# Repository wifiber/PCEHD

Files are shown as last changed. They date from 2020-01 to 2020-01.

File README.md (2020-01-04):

PC Engine / Turbo Grafx HDMI output board (PCEHD)
==============

Overview
--------------------------
PCEHD is a project to deliver HDMI video/audio from the PC Engine/Turbo-Grafx utilizing the digital video bus exposed on the expansion connector. The goal is to take the digital video directly from the console and upscale it to 1080p.

Features
--------------------------
* None yet

TODO
--------------------------
* Finish initial verion of schematic (DONE)
* Finish initial verion of HDL code (need help here)
* Get test PCBs made (PENDING)
* Get HDMI video output working (PENDING)
* Get analog audio encoded into HDMI stream (PENDING)

Long Term TODO
--------------------------
* Optical Drive Emulation (PENDING)
* Flash cart / SD card option (PENDING)

Installation
--------------------------
Attach PCEHD to the expansion port on your PC Engine or Turbo-Grafx console. Enjoy lag free 1080p.

Usage
--------------------------

More info and discussion
--------------------------
See the docs folder for a collection of PC Engine dev material.
There are good schematics online and the TurboGrafx-16 Unit Service Manual provides an excellent block diagram that really makes understanding the interaction of the 3 main HuC62xx chips much easier.

The aim of the PCEHD project is to reproduce the IC112 (HuC6260) inside the FPGA on the PCEHD. HuC6260, the Video Color Encoder, has an internal palette used for the background and sprites. It is made up of 512 9-bit entries. The first 256 entries are for the backgrounds and the last 256 are for the sprites. 
When the console first boots up, the VCE is initialized with palette data from the Hu Card by the CPU. According to the schematics, the data lines from the HU card all have pull-ups to 5v. This is why when you start the console with no game inserted you get a white screen - the VCE palette get filled with all 0xFF for the RGB data, which then returns white on the screen.

Requirement 1. - The FPGA needs to snoop on the CPU -> VCE communication when the console first boots. The FPGA needs to see what the CPU is loading into the VCE internal palette (All 512 entries). This is possible since both the data and address bus are exposed on the expansion connector. So the FPGA should have insight to the CPU -> VCE communication.
Using the FPGA core for the HuC6260, if we are connected to the same address and data bus as the physical VCE, we should be able to get the CPU to update both the physical VCE and the FPGA-VCE at the same time, since the FPGA-VCE is listening at the same address as the VCE inside the console.  

Once the console boots up and the CPU has successfully loaded the VCE pallette, the VDC now comes into play. The VDC and VCE share a 9-bit video bus (This is separate from the data bus the CPU used to load the palette in the steps above). 
The VDC will be placing data on the video bus, this data is a 9-bit address into the VCE palette (9-bits = 512 entries). The VCE takes these addresses, does the lookup into its palette and returns the 9-bit RGB code.  

Requirement 2. - The FPGA needs to snoop on the VDC -> VCE communication. The VDC will be placing addresses on the video bus. Those addresses reference colors stored in the 512 entry VCE palette table. Once the VCE looks up the address, the data it returns is 9-bit RGB data. This 9-bit RGB data is used inside the HuC6260 to generate the analog RGB and composite signals. Assuming the FPGA knows what RGB values are stored in each VCE table entry.(Req 1)
Also, assuming the FPGA knows what the VCE will display next based on what palette address the VDC was placing on the video bus - we should be able to recreate the scanline that the VCE would have displayed. From there its a matter of line-doubling and tweaking to fit the 1080p standard.
Again, using the FPGA core for the HuC6260 should give us a VCE that acts just like the phyiscal one inside the console. Once we have the VCE outputting the RGB data, its a matter of formatting it into the correct HDMI standard.

Thanks to marqs for the OSSC/CPS2_HDMI projects that are the majority of the base material for this project
https://github.com/marqs85

Thanks to the FPGAPCE project on github for a nice HDL example of the entire console.
https://github.com/Torlus/FPGAPCE

Thanks to skum for the very clean and well layed out KiCad symbol and footprint of the expansion connector. Its 69 pins but somehow his symbol is manageable.
https://github.com/skumlos/pcengine-rgb-addon

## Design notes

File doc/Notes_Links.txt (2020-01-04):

https://www.thingiverse.com/thing:3245238
https://oshpark.com/shared_projects/jqp6SYQ6

Exp Port Connector
U1 3x23 Pin 2.54mm pitch header. 
Samtec SSQ-123-02-T-T-RA, SSW-123-02-T-T-RA (or -F-T-RA versions).

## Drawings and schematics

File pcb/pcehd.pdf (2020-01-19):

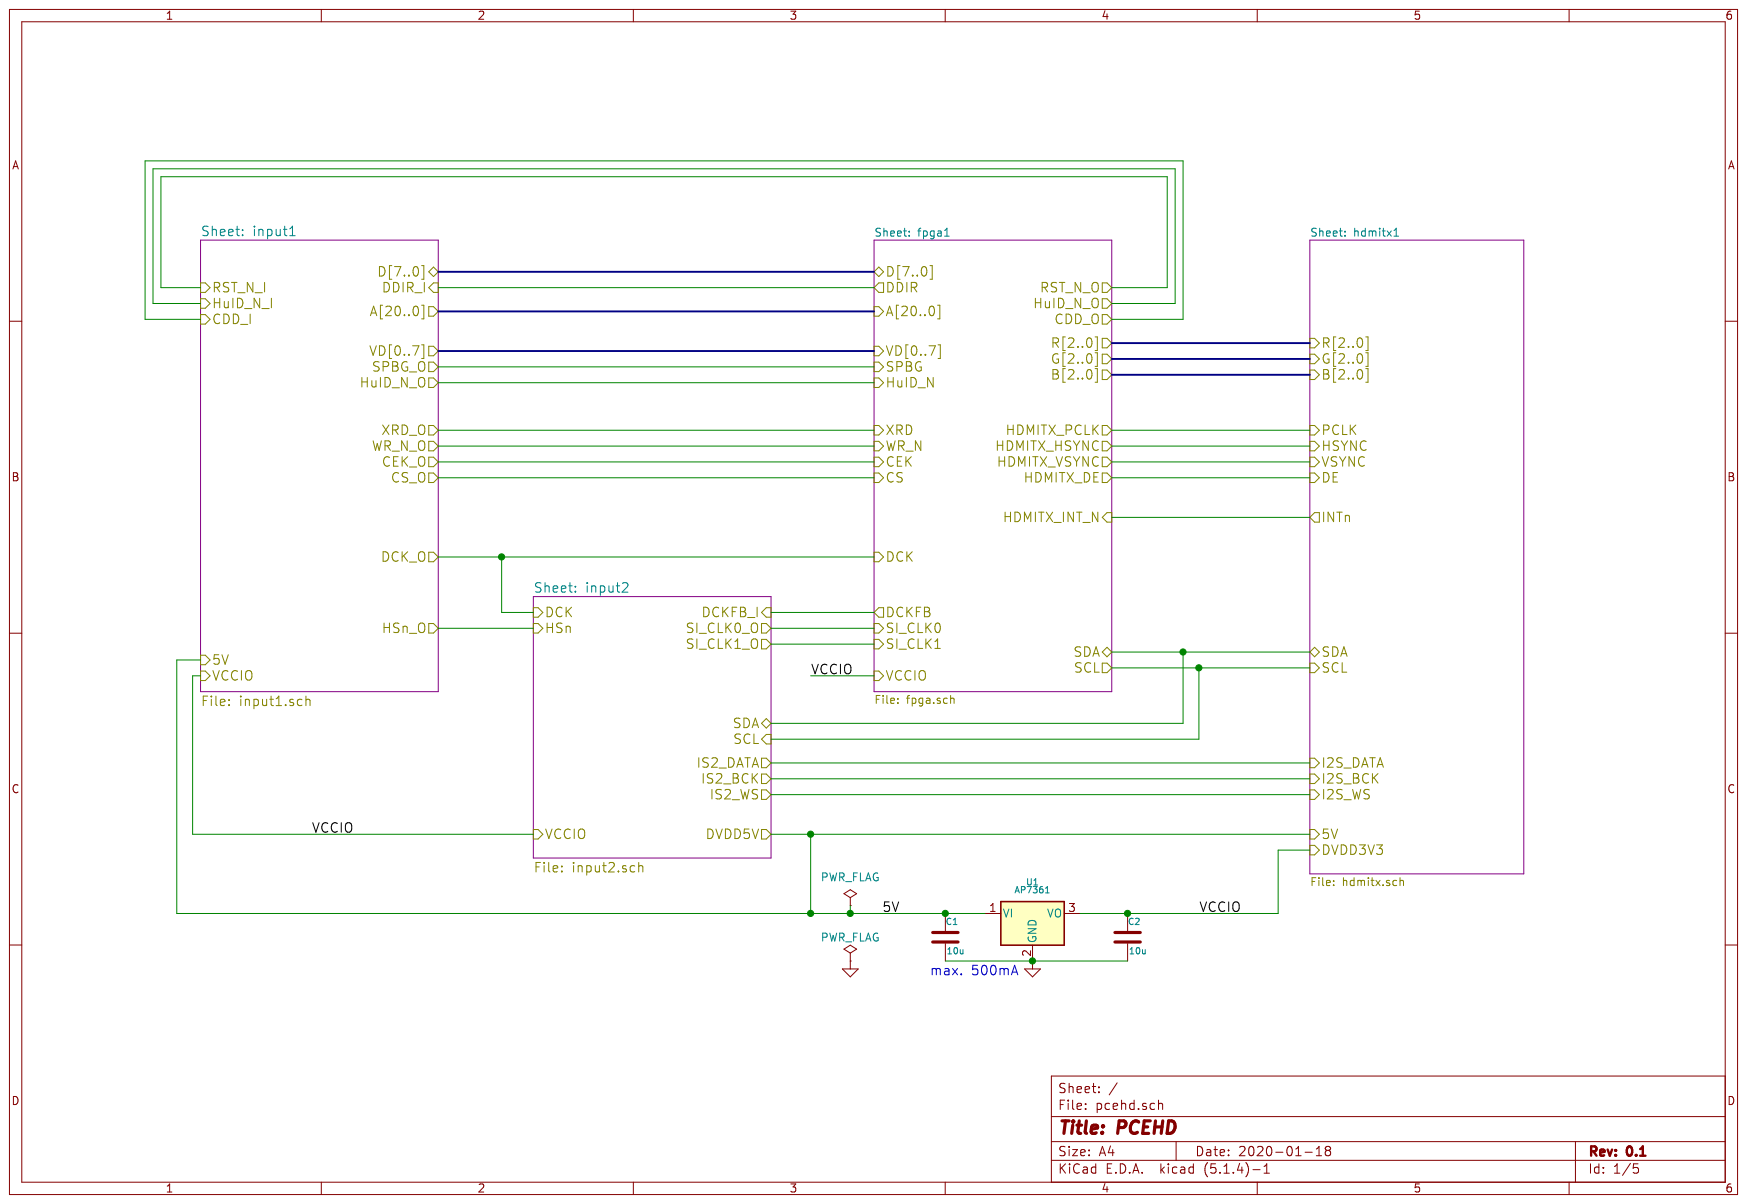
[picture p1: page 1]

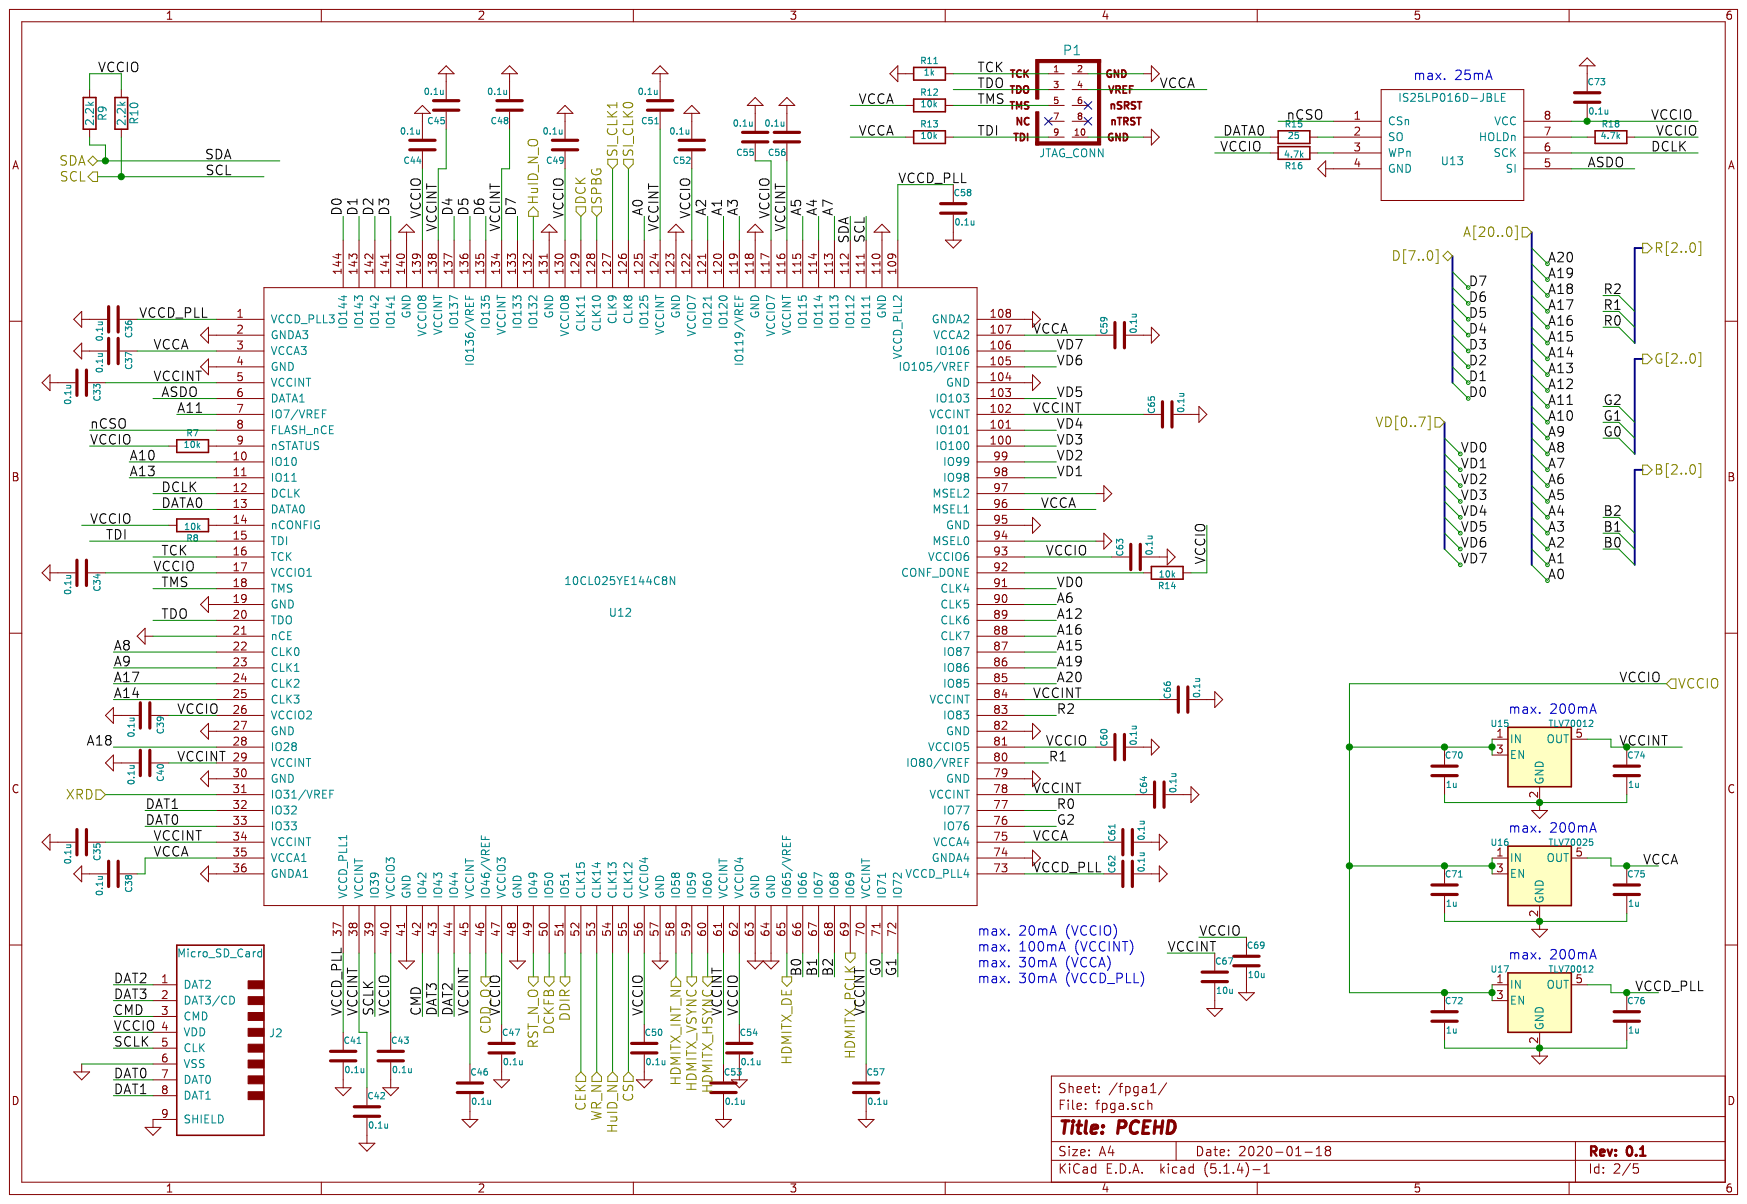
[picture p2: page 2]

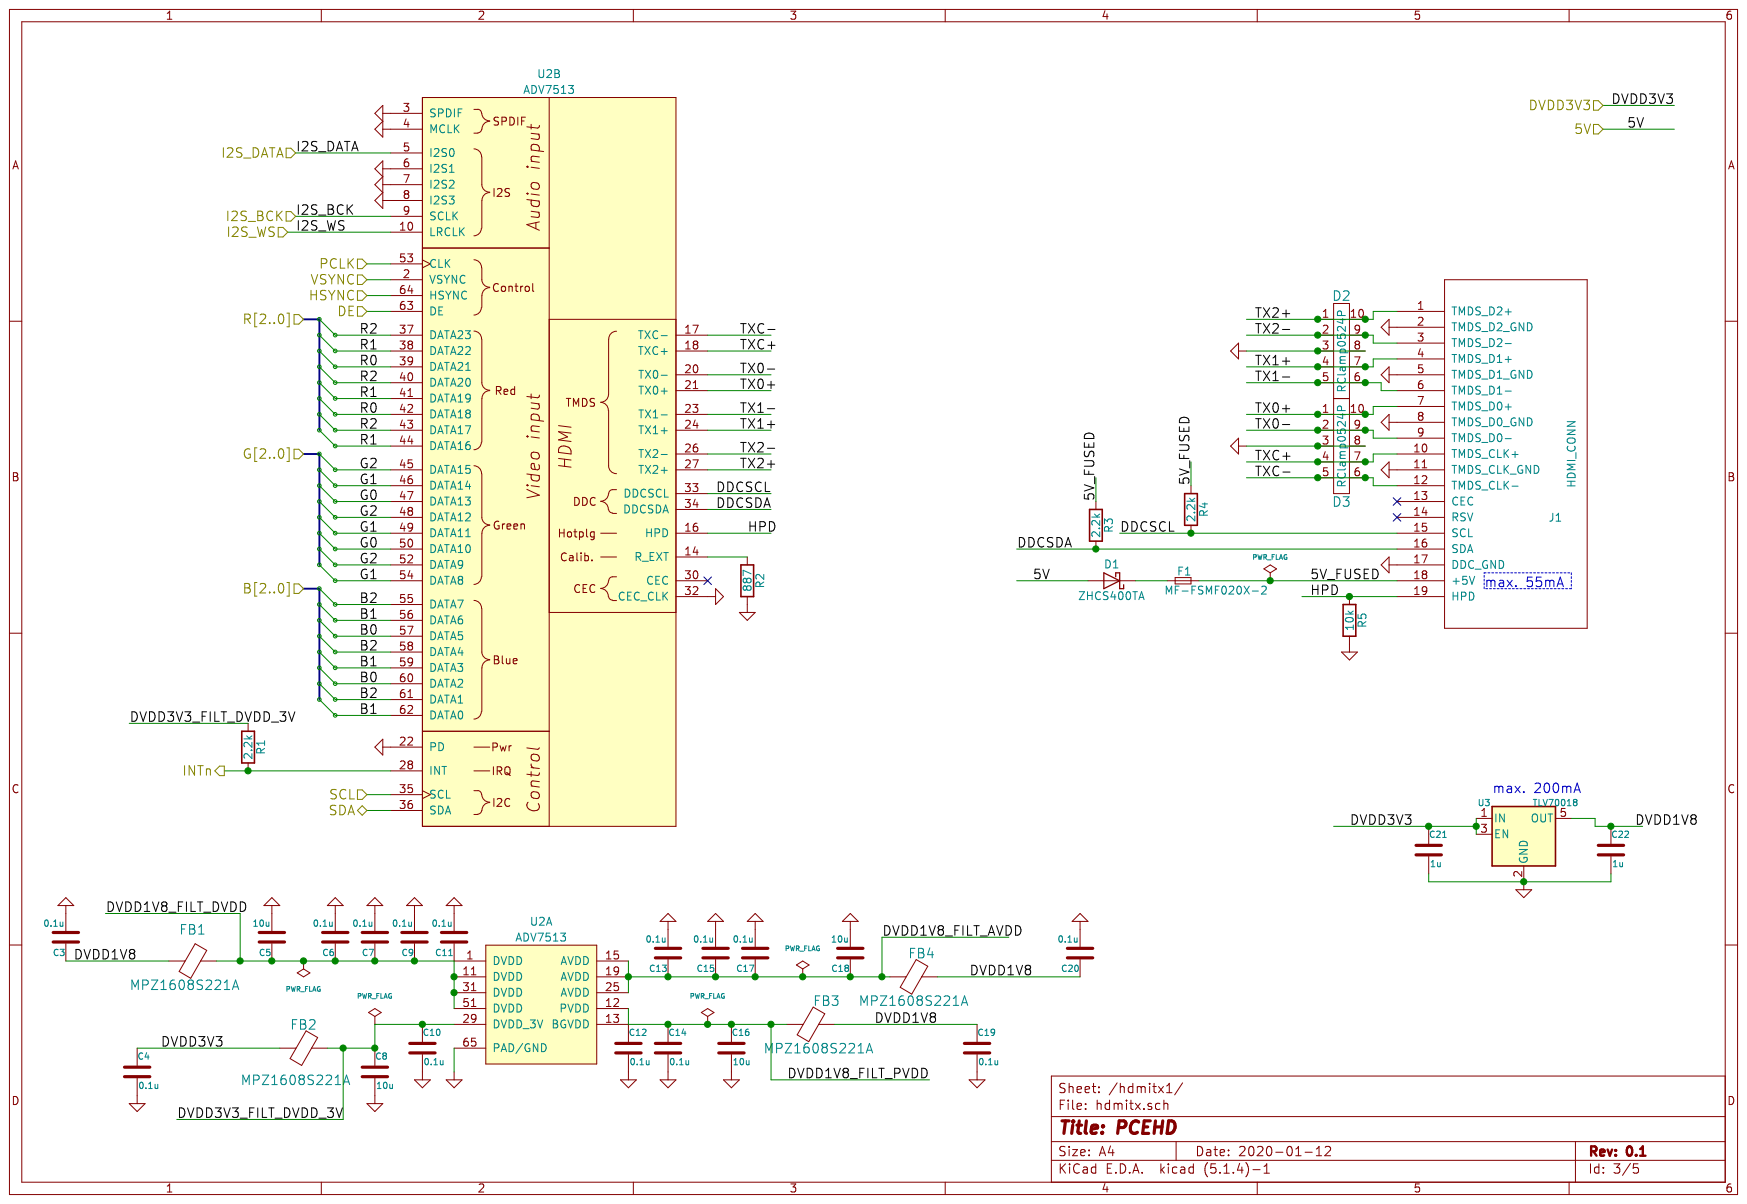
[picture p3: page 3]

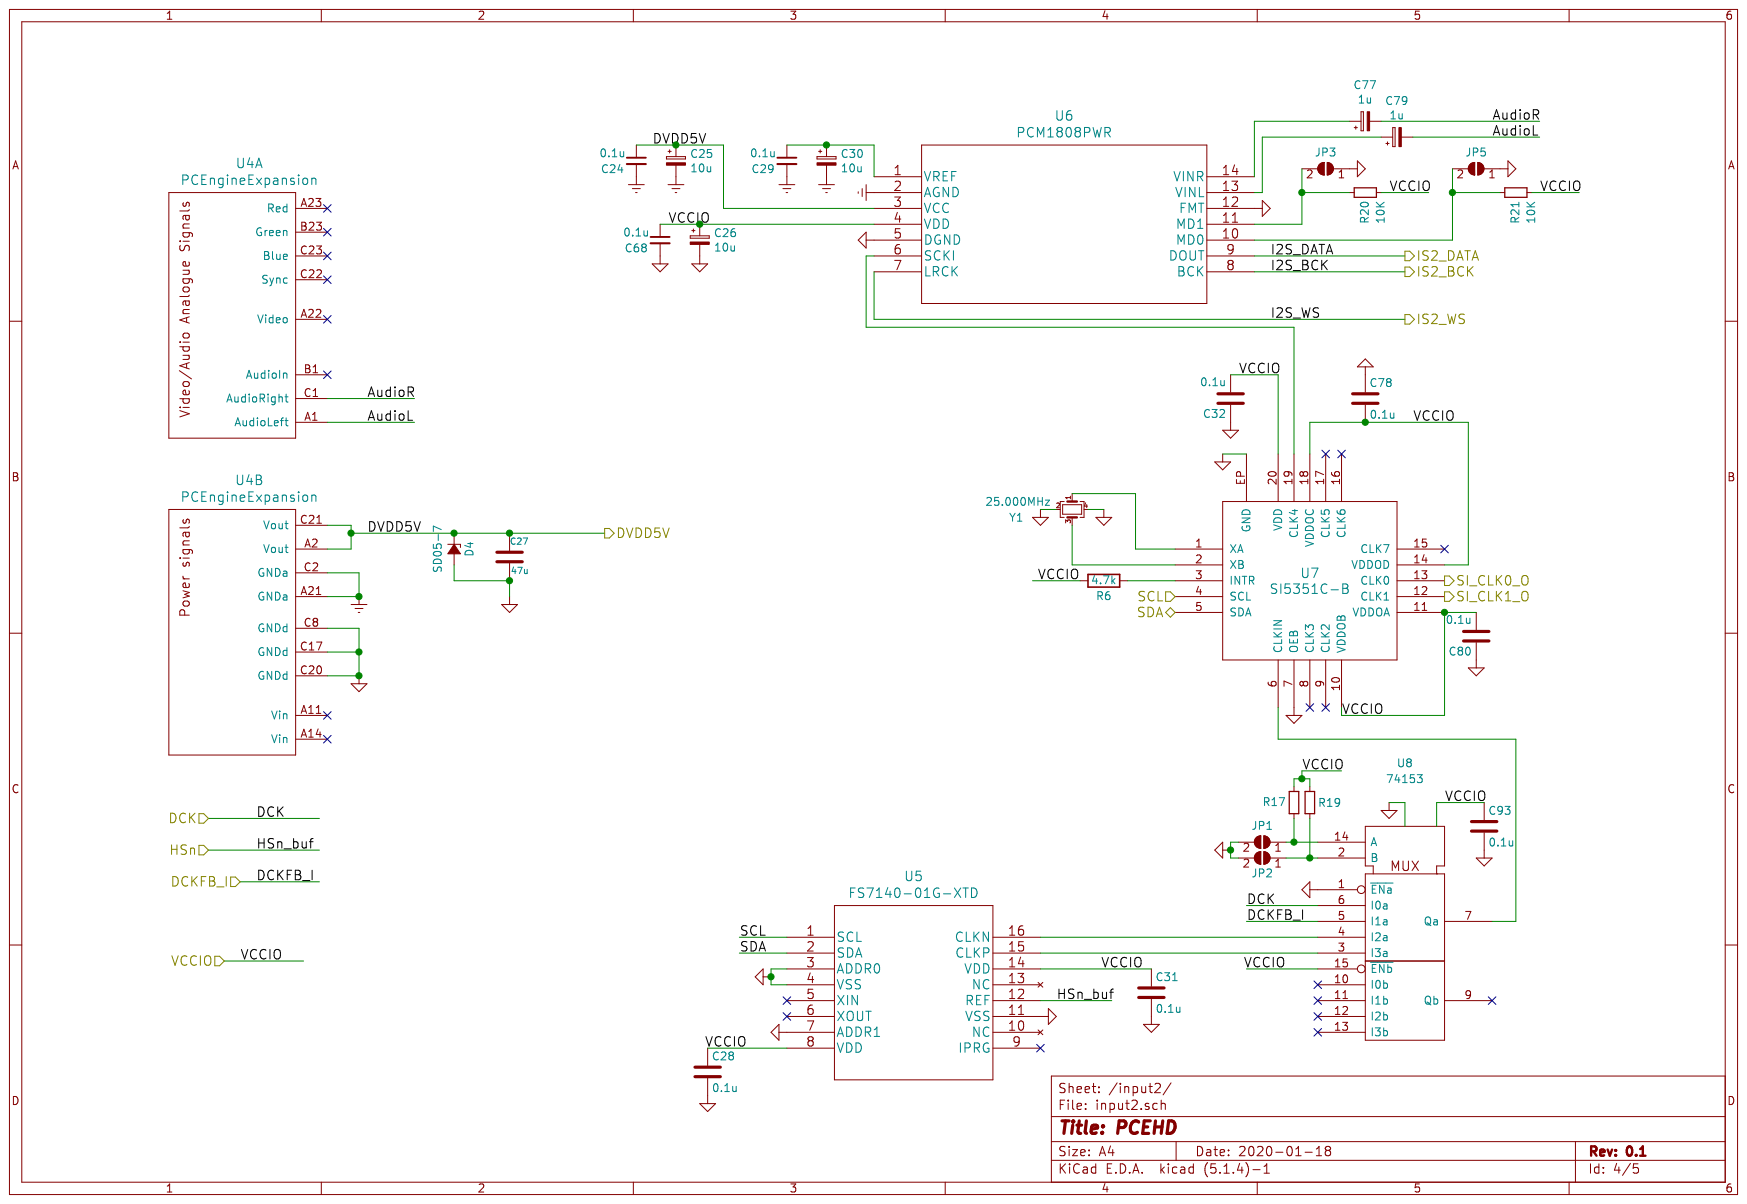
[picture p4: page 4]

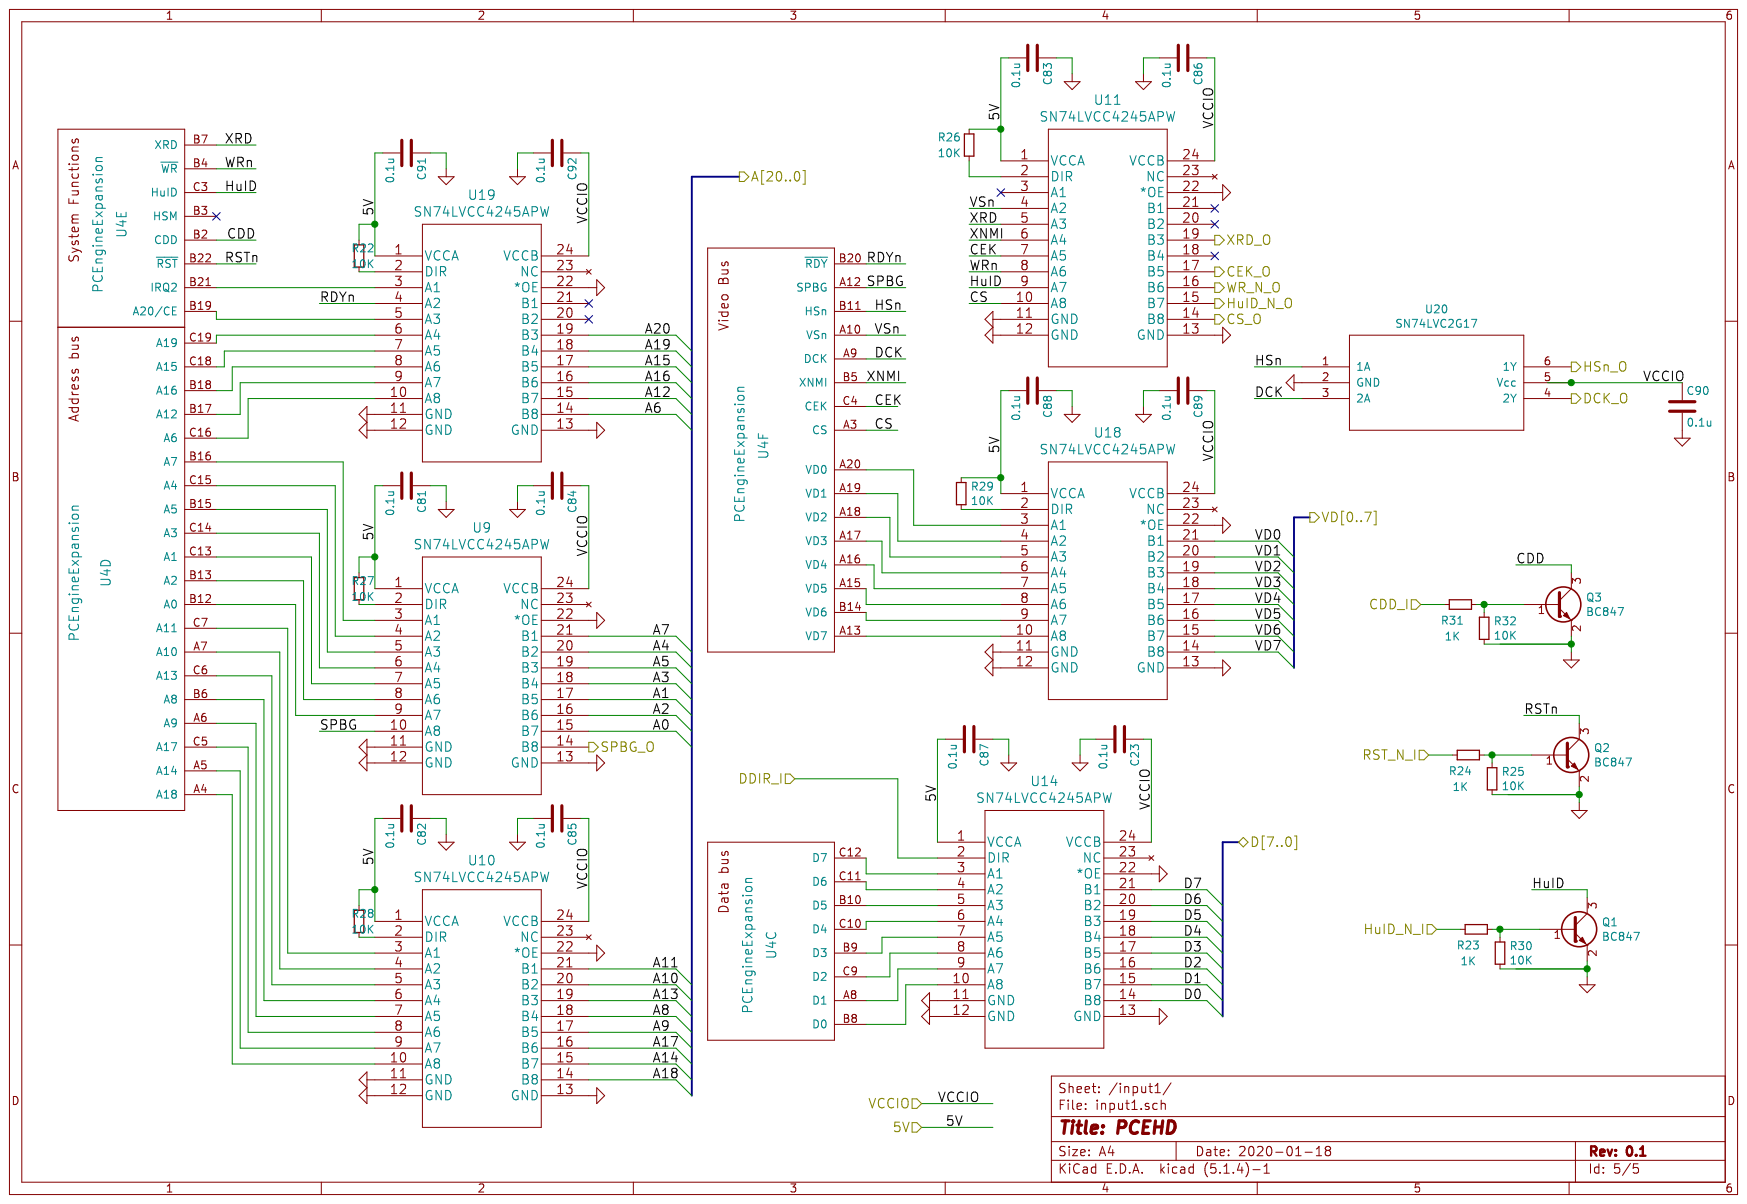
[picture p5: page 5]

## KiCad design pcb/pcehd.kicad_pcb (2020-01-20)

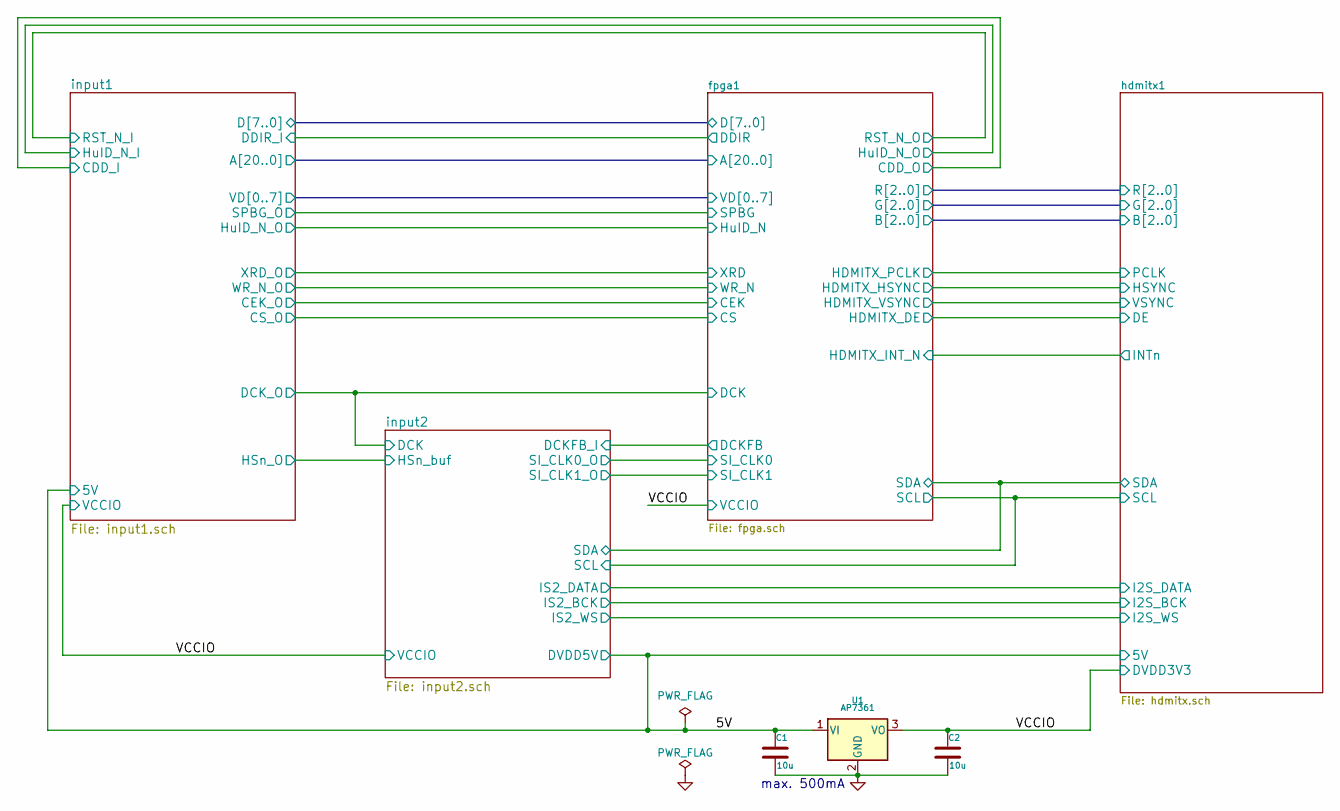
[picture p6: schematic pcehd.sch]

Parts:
C1, C2: 10u; SM0603_Capa_libcms
U1: AP7361; SOT-223_Handsoldering

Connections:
/5V: C1.1, U1.1 (VI); also elsewhere on the board
GND: C1.2, C2.2, U1.2 (GND); also elsewhere on the board
VCC: C2.1, U1.3 (VO); also elsewhere on the board

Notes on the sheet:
max. 500mA

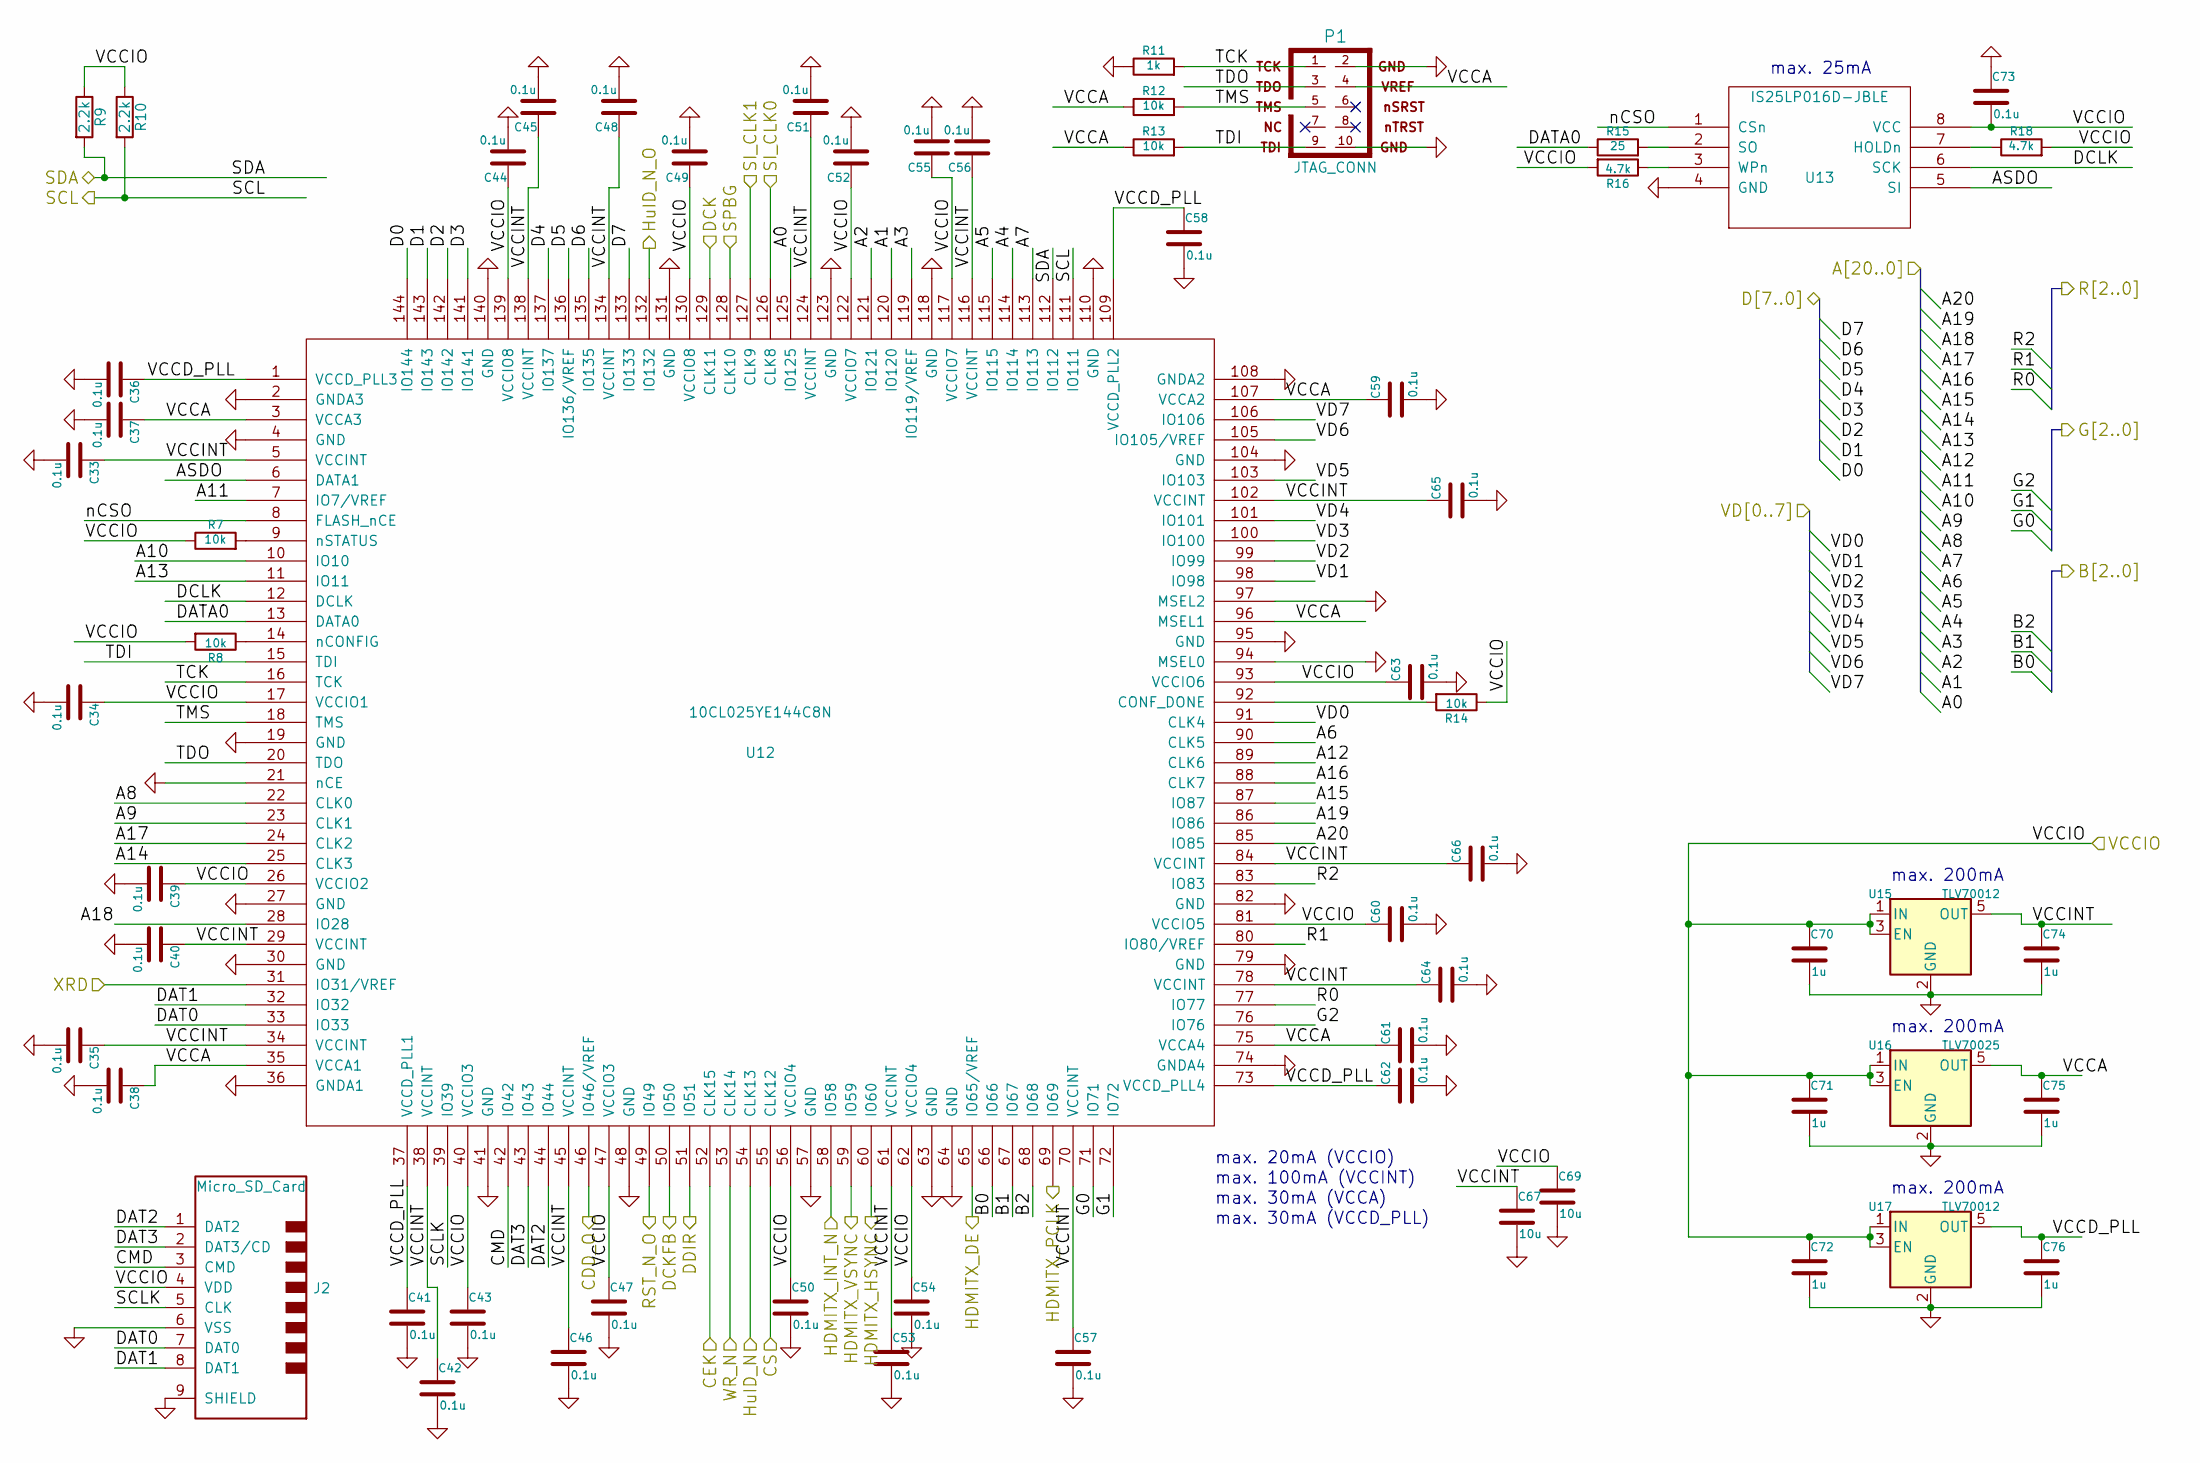
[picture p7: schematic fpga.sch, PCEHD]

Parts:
C33, C34, C35, C36, C37, C38, C39, C40, C41, C42, C43, C44, C45, C46, C47, C48, C49, C50, C51, C52, C53, C54, C55, C56, C57, C58, C59, C60, C61, C62, C63, C64, C65, C66, C73: 0.1u; SM0603_Capa_libcms
C67, C69: 10u; SM0603_Capa_libcms
C70, C71, C72, C74, C75, C76: 1u; SM0603_Capa_libcms
J2: Micro_SD_Card; microSD_HC_Hirose_DM3D-SF
P1: JTAG_CONN; IDC-Header_2x05_P2.54mm_Vertical
R7, R8, R12, R13, R14: 10k; SM0603_Resistor_libcms
R9, R10: 2.2k; SM0603_Resistor_libcms
R11: 1k; SM0603_Resistor_libcms
R15: 25; SM0603_Resistor_libcms
R16, R18: 4.7k; SM0603_Resistor_libcms
U12: 10CL025YE144C8N; TQFP-144_thermal
U13: IS25LP016D-JBLE; SOIC-8_3.9x4.9mm_Pitch1.27mm_Handsoldering
U15, U17: TLV70012; SOT-23-5_Handsoldering
U16: TLV70025; SOT-23-5_Handsoldering

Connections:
/fpga1/A0: U12.125 (IO125); also elsewhere on the board
/fpga1/A1: U12.120 (IO120); also elsewhere on the board
/fpga1/A2: U12.121 (IO121); also elsewhere on the board
/fpga1/A3: U12.119 (IO119/VREF); also elsewhere on the board
/fpga1/A4: U12.114 (IO114); also elsewhere on the board
/fpga1/A5: U12.115 (IO115); also elsewhere on the board
/fpga1/A6: U12.90 (CLK5); also elsewhere on the board
/fpga1/A7: U12.113 (IO113); also elsewhere on the board
/fpga1/A8: U12.22 (CLK0); also elsewhere on the board
/fpga1/A9: U12.23 (CLK1); also elsewhere on the board
/fpga1/A10: U12.10 (IO10); also elsewhere on the board
/fpga1/A11: U12.7 (IO7/VREF); also elsewhere on the board
/fpga1/A12: U12.89 (CLK6); also elsewhere on the board
/fpga1/A13: U12.11 (IO11); also elsewhere on the board
/fpga1/A14: U12.25 (CLK3); also elsewhere on the board
/fpga1/A15: U12.87 (IO87); also elsewhere on the board
/fpga1/A16: U12.88 (CLK7); also elsewhere on the board
/fpga1/A17: U12.24 (CLK2); also elsewhere on the board
/fpga1/A18: U12.28 (IO28); also elsewhere on the board
/fpga1/A19: U12.86 (IO86); also elsewhere on the board
/fpga1/A20: U12.85 (IO85); also elsewhere on the board
/fpga1/ASDO: U12.6 (DATA1), U13.5 (SI)
/fpga1/B0: U12.66 (IO66); also elsewhere on the board
/fpga1/B1: U12.67 (IO67); also elsewhere on the board
/fpga1/B2: U12.68 (IO68); also elsewhere on the board
/fpga1/CEK: U12.52 (CLK15); also elsewhere on the board
/fpga1/CMD: J2.3 (CMD), U12.42 (IO42)
/fpga1/CS: U12.55 (CLK12); also elsewhere on the board
/fpga1/D0: U12.144 (IO144); also elsewhere on the board
/fpga1/D1: U12.143 (IO143); also elsewhere on the board
/fpga1/D2: U12.142 (IO142); also elsewhere on the board
/fpga1/D3: U12.141 (IO141); also elsewhere on the board
/fpga1/D4: U12.137 (IO137); also elsewhere on the board
/fpga1/D5: U12.136 (IO136/VREF); also elsewhere on the board
/fpga1/D6: U12.135 (IO135); also elsewhere on the board
/fpga1/D7: U12.133 (IO133); also elsewhere on the board
/fpga1/DAT0: J2.7 (DAT0), U12.33 (IO33)
/fpga1/DAT1: J2.8 (DAT1), U12.32 (IO32)
/fpga1/DAT2: J2.1 (DAT2), U12.44 (IO44)
/fpga1/DAT3: J2.2 (DAT3/CD), U12.43 (IO43)
/fpga1/DATA0: R15.1, U12.13 (DATA0)
/fpga1/DCK: U12.129 (CLK11); also elsewhere on the board
/fpga1/DCKFB: U12.50 (IO50); also elsewhere on the board
/fpga1/DCLK: U12.12 (DCLK), U13.6 (SCK)
/fpga1/DDIR: U12.51 (IO51); also elsewhere on the board
/fpga1/G0: U12.71 (IO71); also elsewhere on the board
/fpga1/G1: U12.72 (IO72); also elsewhere on the board
/fpga1/G2: U12.76 (IO76); also elsewhere on the board
/fpga1/HDMITX_HSYNC: U12.60 (IO60); also elsewhere on the board
/fpga1/HDMITX_INT_N: U12.58 (IO58); also elsewhere on the board
/fpga1/HDMITX_PCLK: U12.69 (IO69); also elsewhere on the board
/fpga1/HDMITX_VSYNC: U12.59 (IO59); also elsewhere on the board
/fpga1/HuID_N: U12.54 (CLK13); also elsewhere on the board
/fpga1/R0: U12.77 (IO77); also elsewhere on the board
/fpga1/R1: U12.80 (IO80/VREF); also elsewhere on the board
/fpga1/R2: U12.83 (IO83); also elsewhere on the board
/fpga1/SCL: R10.2, U12.111 (IO111); also elsewhere on the board
/fpga1/SCLK: J2.5 (CLK), U12.39 (IO39)
/fpga1/SDA: R9.2, U12.112 (IO112); also elsewhere on the board
/fpga1/SI_CLK0: U12.126 (CLK8); also elsewhere on the board
/fpga1/SI_CLK1: U12.127 (CLK9); also elsewhere on the board
/fpga1/SPBG: U12.128 (CLK10); also elsewhere on the board
/fpga1/TCK: P1.1, R11.2, U12.16 (TCK)
/fpga1/TDI: P1.9, R13.2, U12.15 (TDI)
/fpga1/TDO: P1.3, U12.20 (TDO)
/fpga1/TMS: P1.5, R12.2, U12.18 (TMS)
/fpga1/VCCA: C37.1, C38.1, C59.1, C61.1, C75.1, P1.4, R12.1, R13.1, U12.3 (VCCA3), U12.35 (VCCA1), U12.75 (VCCA4), U12.96 (MSEL1), U12.107 (VCCA2), U16.5 (OUT)
/fpga1/VCCD_PLL: C36.1, C41.1, C58.1, C62.1, C76.1, U12.1 (VCCD_PLL3), U12.37 (VCCD_PLL1), U12.73 (VCCD_PLL4), U12.109 (VCCD_PLL2), U17.5 (OUT)
/fpga1/VCCINT: C33.1, C35.1, C40.1, C42.1, C45.1, C46.1, C48.1, C51.1, C53.1, C56.1, C57.1, C64.1, C65.1, C66.1, C67.1, C74.1, U12.5 (VCCINT), U12.29 (VCCINT), U12.34 (VCCINT), U12.38 (VCCINT), U12.45 (VCCINT), U12.61 (VCCINT), U12.70 (VCCINT), U12.78 (VCCINT), U12.84 (VCCINT), U12.102 (VCCINT), U12.116 (VCCINT), U12.124 (VCCINT), U12.134 (VCCINT), U12.138 (VCCINT), U15.5 (OUT)
/fpga1/VD0: U12.91 (CLK4); also elsewhere on the board
/fpga1/VD1: U12.98 (IO98); also elsewhere on the board
/fpga1/VD2: U12.99 (IO99); also elsewhere on the board
/fpga1/VD3: U12.100 (IO100); also elsewhere on the board
/fpga1/VD4: U12.101 (IO101); also elsewhere on the board
/fpga1/VD5: U12.103 (IO103); also elsewhere on the board
/fpga1/VD6: U12.105 (IO105/VREF); also elsewhere on the board
/fpga1/VD7: U12.106 (IO106); also elsewhere on the board
/fpga1/WR_N: U12.53 (CLK14); also elsewhere on the board
/fpga1/XRD: U12.31 (IO31/VREF); also elsewhere on the board
/fpga1/nCSO: U12.8 (FLASH_nCE), U13.1 (CSn)
/hdmitx1/DE: U12.65 (IO65/VREF); also elsewhere on the board
/input1/CDD_I: U12.46 (IO46/VREF); also elsewhere on the board
/input1/HuID_N_I: U12.132 (IO132); also elsewhere on the board
/input1/RST_N_I: U12.49 (IO49); also elsewhere on the board
GND: C33.2, C34.2, C35.2, C36.2, C37.2, C38.2, C39.2, C40.2, C41.2, C42.2, C43.2, C44.2, C45.2, C46.2, C47.2, C48.2, C49.2, C50.2, C51.2, C52.2, C53.2, C54.2, C55.2, C56.2, C57.2, C58.2, C59.2, C60.2, C61.2, C62.2, C63.2, C64.2, C65.2, C66.2, C67.2, C69.2, C70.2, C71.2, C72.2, C73.1, C74.2, C75.2, C76.2, J2.6 (VSS), J2.9 (SHIELD), P1.2, P1.10, R11.1, U12.2 (GNDA3), U12.4 (GND), U12.19 (GND), U12.21 (nCE), U12.27 (GND), U12.30 (GND), U12.36 (GNDA1), U12.41 (GND), U12.48 (GND), U12.57 (GND), U12.63 (GND), U12.64 (GND), U12.74 (GNDA4), U12.79 (GND), U12.82 (GND), U12.94 (MSEL0), U12.95 (GND), U12.97 (MSEL2), U12.104 (GND), U12.108 (GNDA2), U12.110 (GND), U12.118 (GND), U12.123 (GND), U12.131 (GND), U12.140 (GND), U13.4 (GND), U15.2 (GND), U16.2 (GND), U17.2 (GND); also elsewhere on the board
unnamed: R7.2, U12.9 (nSTATUS)
unnamed: R8.1, U12.14 (nCONFIG)
unnamed: R14.2, U12.92 (CONF_DONE)
unnamed: R15.2, U13.2 (SO)
unnamed: R16.1, U13.3 (WPn)
unnamed: R18.1, U13.7 (HOLDn)
VCC: C34.1, C39.1, C43.1, C44.1, C47.1, C49.1, C50.1, C52.1, C54.1, C55.1, C60.1, C63.1, C69.1, C70.1, C71.1, C72.1, C73.2, J2.4 (VDD), R7.1, R8.2, R9.1, R10.1, R14.1, R16.2, R18.2, U12.17 (VCCIO1), U12.26 (VCCIO2), U12.40 (VCCIO3), U12.47 (VCCIO3), U12.56 (VCCIO4), U12.62 (VCCIO4), U12.81 (VCCIO5), U12.93 (VCCIO6), U12.117 (VCCIO7), U12.122 (VCCIO7), U12.130 (VCCIO8), U12.139 (VCCIO8), U13.8 (VCC), U15.1 (IN), U15.3 (EN), U16.1 (IN), U16.3 (EN), U17.1 (IN), U17.3 (EN); also elsewhere on the board

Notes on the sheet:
max. 200mA
max. 25mA
max. 20mA (VCCIO)
max. 100mA (VCCINT)
max. 30mA (VCCA)
max. 30mA (VCCD_PLL)

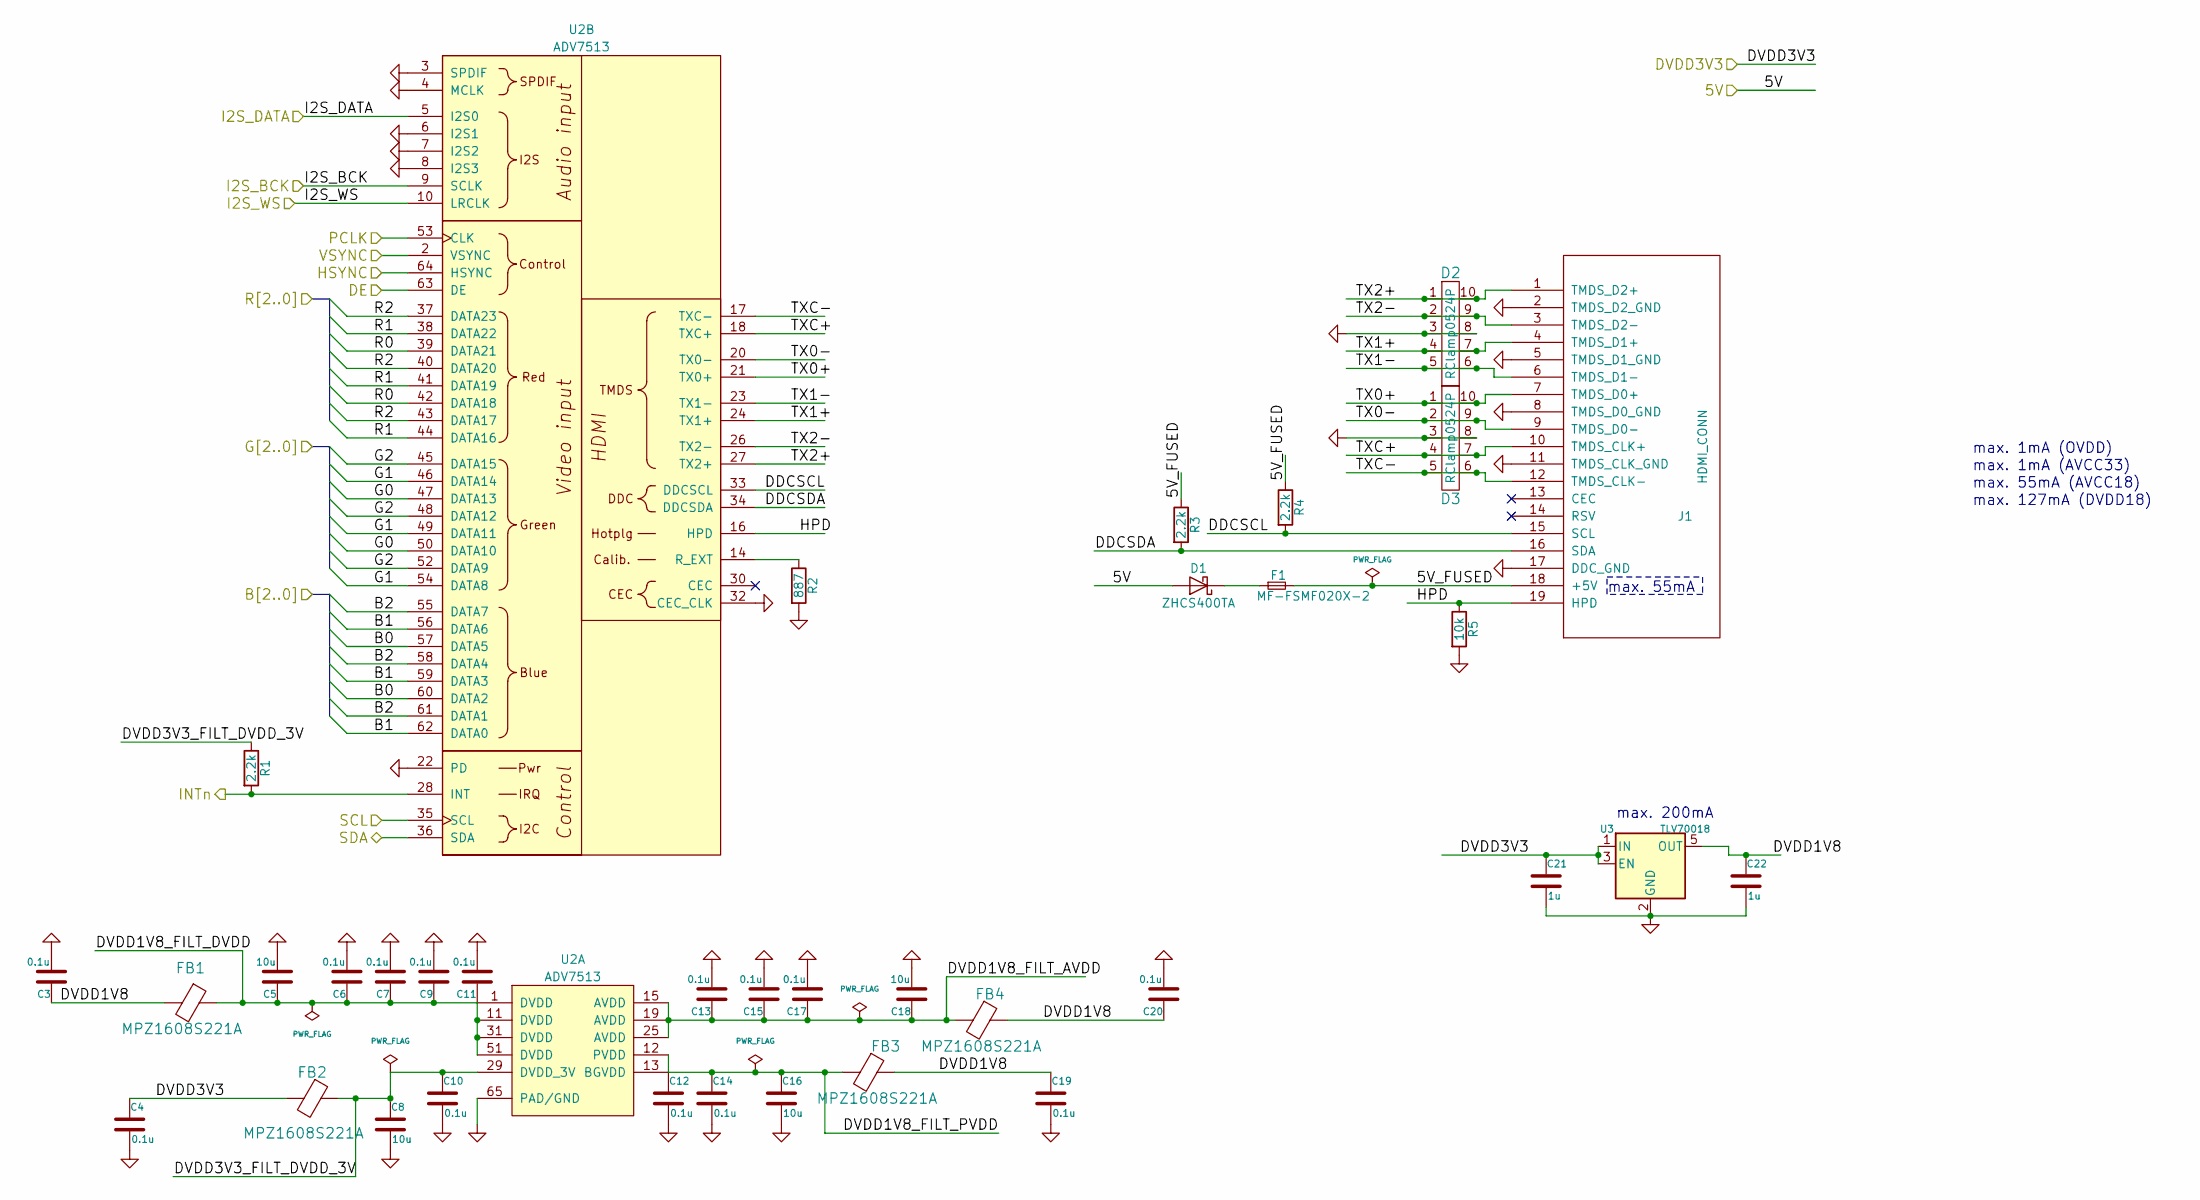
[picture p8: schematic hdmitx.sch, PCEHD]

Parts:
C3, C4, C6, C7, C9, C10, C11, C12, C13, C14, C15, C17, C19, C20: 0.1u; SM0603_Capa_libcms
C5, C8, C16, C18: 10u; SM0603_Capa_libcms
C21, C22: 1u; SM0603_Capa_libcms
D1: ZHCS400TA; SOD-323_Handsoldering
D2, D3: RClamp0524P; SLP2510P8
F1: MF-FSMF020X-2; SM0603_Resistor_libcms
FB1, FB2, FB3, FB4: MPZ1608S221A; SM0603_Resistor_libcms
J1: HDMI_CONN; HDMI_CONN-10029449-111RLF; Part ID 10029449-111RLF
R1, R3, R4: 2.2k; SM0603_Resistor_libcms
R2: 887; SM0603_Resistor_libcms
R5: 10k; SM0603_Resistor_libcms
U2: ADV7513; LQFP-64-1EP_10x10mm_Pitch0.5mm_Handsoldering
U3: TLV70018; SOT-23-5_Handsoldering

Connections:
/5V: D1.2 (A); also elsewhere on the board
/fpga1/B0: U2.57 (DATA5), U2.60 (DATA2); also elsewhere on the board
/fpga1/B1: U2.56 (DATA6), U2.59 (DATA3), U2.62 (DATA0); also elsewhere on the board
/fpga1/B2: U2.55 (DATA7), U2.58 (DATA4), U2.61 (DATA1); also elsewhere on the board
/fpga1/G0: U2.47 (DATA13), U2.50 (DATA10); also elsewhere on the board
/fpga1/G1: U2.46 (DATA14), U2.49 (DATA11), U2.54 (DATA8); also elsewhere on the board
/fpga1/G2: U2.45 (DATA15), U2.48 (DATA12), U2.52 (DATA9); also elsewhere on the board
/fpga1/HDMITX_HSYNC: U2.64 (HSYNC); also elsewhere on the board
/fpga1/HDMITX_INT_N: R1.2, U2.28 (INT); also elsewhere on the board
/fpga1/HDMITX_PCLK: U2.53 (CLK); also elsewhere on the board
/fpga1/HDMITX_VSYNC: U2.2 (VSYNC); also elsewhere on the board
/fpga1/R0: U2.39 (DATA21), U2.42 (DATA18); also elsewhere on the board
/fpga1/R1: U2.38 (DATA22), U2.41 (DATA19), U2.44 (DATA16); also elsewhere on the board
/fpga1/R2: U2.37 (DATA23), U2.40 (DATA20), U2.43 (DATA17); also elsewhere on the board
/fpga1/SCL: U2.35 (SCL); also elsewhere on the board
/fpga1/SDA: U2.36 (SDA); also elsewhere on the board
/hdmitx1/5V_FUSED: F1.2, J1.18 (+5V), R3.1, R4.1
/hdmitx1/DDCSCL: J1.15 (SCL), R4.2, U2.33 (DDCSCL)
/hdmitx1/DDCSDA: J1.16 (SDA), R3.2, U2.34 (DDCSDA)
/hdmitx1/DE: U2.63 (DE); also elsewhere on the board
/hdmitx1/DVDD1V8: C3.1, C19.1, C20.1, C22.1, FB1.2, FB3.1, FB4.1, U3.5 (OUT)
/hdmitx1/DVDD1V8_FILT_AVDD: C13.1, C15.1, C17.1, C18.1, FB4.2, U2.15 (AVDD), U2.19 (AVDD), U2.25 (AVDD)
/hdmitx1/DVDD1V8_FILT_DVDD: C5.1, C6.1, C7.1, C9.1, C11.1, FB1.1, U2.1 (DVDD), U2.11 (DVDD), U2.31 (DVDD), U2.51 (DVDD)
/hdmitx1/DVDD1V8_FILT_PVDD: C12.1, C14.1, C16.1, FB3.2, U2.12 (PVDD), U2.13 (BGVDD)
/hdmitx1/DVDD3V3_FILT_DVDD_3V: C8.1, C10.1, FB2.1, R1.1, U2.29 (DVDD_3V)
/hdmitx1/HPD: J1.19 (HPD), R5.1, U2.16 (HPD)
/hdmitx1/I2S_BCK: U2.9 (SCLK); also elsewhere on the board
/hdmitx1/I2S_DATA: U2.5 (I2S0); also elsewhere on the board
/hdmitx1/I2S_WS: U2.10 (LRCLK); also elsewhere on the board
/hdmitx1/TX0+: D3.1, D3.10, J1.7 (TMDS_D0+), U2.21 (TX0+)
/hdmitx1/TX0-: D3.2, D3.9, J1.9 (TMDS_D0-), U2.20 (TX0-)
/hdmitx1/TX1+: D2.4, D2.7, J1.4 (TMDS_D1+), U2.24 (TX1+)
/hdmitx1/TX1-: D2.5, D2.6, J1.6 (TMDS_D1-), U2.23 (TX1-)
/hdmitx1/TX2+: D2.1, D2.10, J1.1 (TMDS_D2+), U2.27 (TX2+)
/hdmitx1/TX2-: D2.2, D2.9, J1.3 (TMDS_D2-), U2.26 (TX2-)
/hdmitx1/TXC+: D3.4, D3.7, J1.10 (TMDS_CLK+), U2.18 (TXC+)
/hdmitx1/TXC-: D3.5, D3.6, J1.12 (TMDS_CLK-), U2.17 (TXC-)
GND: C3.2, C4.2, C5.2, C6.2, C7.2, C8.2, C9.2, C10.2, C11.2, C12.2, C13.2, C14.2, C15.2, C16.2, C17.2, C18.2, C19.2, C20.2, C21.2, C22.2, D2.3, D2.8, D3.3, D3.8, J1.2 (TMDS_D2_GND), J1.5 (TMDS_D1_GND), J1.8 (TMDS_D0_GND), J1.11 (TMDS_CLK_GND), J1.17 (DDC_GND), R2.2, R5.2, U2.3 (SPDIF), U2.4 (MCLK), U2.6 (I2S1), U2.7 (I2S2), U2.8 (I2S3), U2.22 (PD), U2.32 (CEC_CLK), U2.65 (PAD/GND), U3.2 (GND); also elsewhere on the board
unnamed: D1.1 (K), F1.1
unnamed: R2.1, U2.14 (R_EXT)
VCC: C4.1, C21.1, FB2.2, U3.1 (IN), U3.3 (EN); also elsewhere on the board

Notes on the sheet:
max. 200mA
max. 1mA (OVDD)
max. 1mA (AVCC33)
max. 55mA (AVCC18)
max. 127mA (DVDD18)
max. 55mA

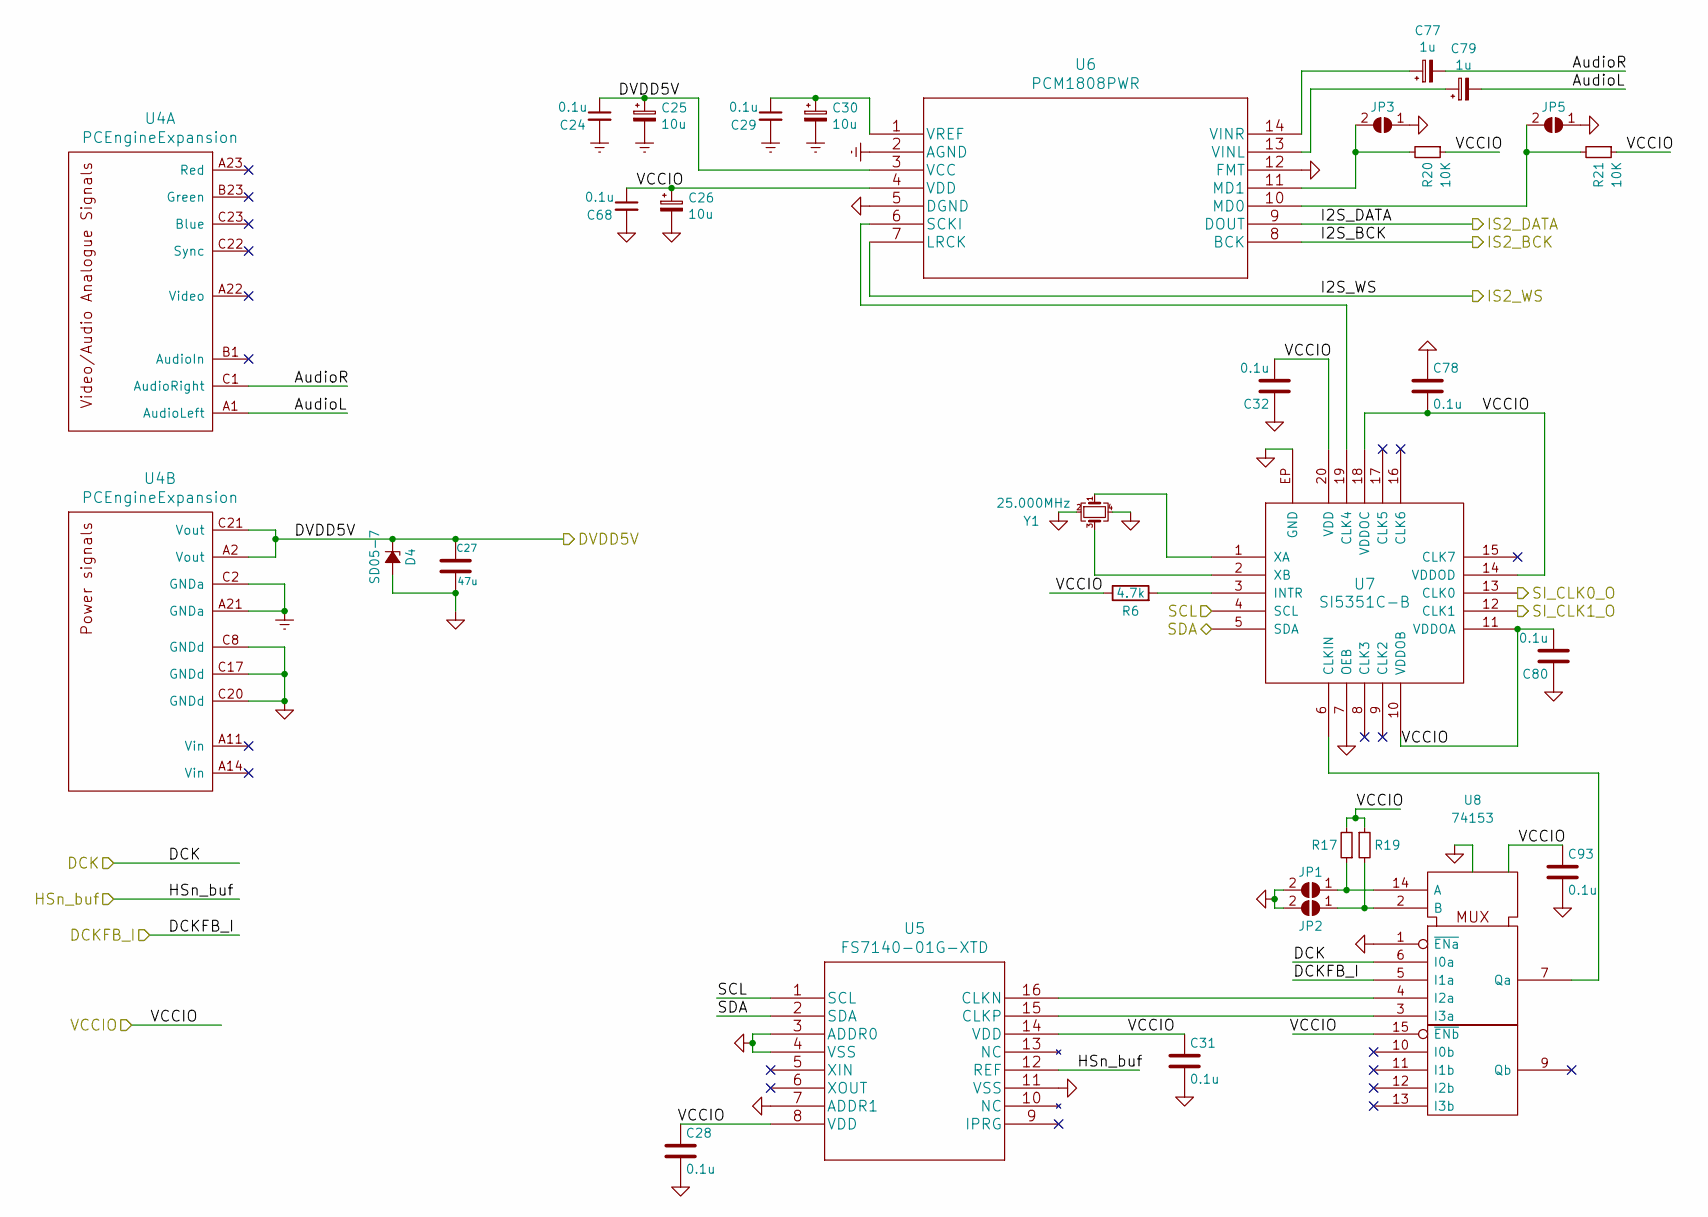
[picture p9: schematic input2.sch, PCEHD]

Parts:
C24, C28, C29, C31, C32, C68, C78, C80, C93: 0.1u; SM0603_Capa_libcms
C25, C26, C30: 10u; SM0603_Capa_libcms
C27: 47u; SM0603_Capa_libcms
C77, C79: 1u; SM0603_Capa_libcms
D4: SD05-7; SOD-323_Handsoldering
JP1, JP2, JP3, JP5: SolderJumper_2_Open; SolderJumper-2_P1.3mm_Open_RoundedPad1.0x1.5mm
R6: 4.7k; SM0603_Resistor_libcms
R17, R19, R20, R21: 10K; SM0603_Resistor_libcms
U4: PCEngineExpansion
U5: FS7140-01G-XTD
U6: PCM1808PWR
U7: SI5351C-B; QFN-20-1EP_4x4mm_Pitch0.5mm_Handsoldering
U8: 74153; SOIC-16_3.9x9.9mm_P1.27mm
Y1: 25.000MHz; Crystal_SMD_SeikoEpson_FA238-4Pin_3.2x2.5mm_HandSoldering

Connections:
/5V: C24.1, C25.1, C27.1, D4.1 (K), U4.A2 (Vout), U4.C21 (Vout), U6.3 (VCC); also elsewhere on the board
/fpga1/DCK: U8.6 (I0a); also elsewhere on the board
/fpga1/DCKFB: U8.5 (I1a); also elsewhere on the board
/fpga1/SCL: U5.1 (SCL), U7.4 (SCL); also elsewhere on the board
/fpga1/SDA: U5.2 (SDA), U7.5 (SDA); also elsewhere on the board
/fpga1/SI_CLK0: U7.13 (CLK0); also elsewhere on the board
/fpga1/SI_CLK1: U7.12 (CLK1); also elsewhere on the board
/hdmitx1/I2S_BCK: U6.8 (BCK); also elsewhere on the board
/hdmitx1/I2S_DATA: U6.9 (DOUT); also elsewhere on the board
/hdmitx1/I2S_WS: U6.7 (LRCK); also elsewhere on the board
/input1/HSn_O: U5.12 (REF); also elsewhere on the board
/input2/AudioL: C79.2, U4.A1 (AudioLeft)
/input2/AudioR: C77.2, U4.C1 (AudioRight)
GND: C26.2, C27.2, C28.2, C31.2, C32.1, C68.2, C78.1, C80.1, C93.2, D4.2 (A), JP1.2 (B), JP2.2 (B), JP3.1 (A), JP5.1 (A), U4.C8 (GNDd), U4.C17 (GNDd), U4.C20 (GNDd), U5.3 (ADDR0), U5.4 (VSS), U5.7 (ADDR1), U5.11 (VSS), U6.5 (DGND), U6.12 (FMT), U7.7 (OEB), U7.EP (GND), U8.1 (~ENa), U8.8 (GND), Y1.2, Y1.4; also elsewhere on the board
GNDREF: C24.2, C25.2, C29.2, C30.2, U4.A21 (GNDa), U4.C2 (GNDa), U6.2 (AGND)
unnamed: C29.1, C30.1, U6.1 (VREF)
unnamed: C77.1, U6.14 (VINR)
unnamed: C79.1, U6.13 (VINL)
unnamed: JP1.1 (A), R17.1, U8.14 (A)
unnamed: JP2.1 (A), R19.2, U8.2 (B)
unnamed: JP3.2 (B), R20.2, U6.11 (MD1)
unnamed: JP5.2 (B), R21.2, U6.10 (MD0)
unnamed: R6.2, U7.3 (INTR)
unnamed: U5.15 (CLKP), U8.3 (I3a)
unnamed: U5.16 (CLKN), U8.4 (I2a)
unnamed: U6.6 (SCKI), U7.19 (CLK4)
unnamed: U7.1 (XA), Y1.1
unnamed: U7.2 (XB), Y1.3
unnamed: U7.6 (CLKIN), U8.7 (Qa)
VCC: C26.1, C28.1, C31.1, C32.2, C68.1, C78.2, C80.2, C93.1, R6.1, R17.2, R19.1, R20.1, R21.1, U5.8 (VDD), U5.14 (VDD), U6.4 (VDD), U7.10 (VDDOB), U7.11 (VDDOA), U7.14 (VDDOD), U7.18 (VDDOC), U7.20 (VDD), U8.15 (~ENb), U8.16 (VCC); also elsewhere on the board

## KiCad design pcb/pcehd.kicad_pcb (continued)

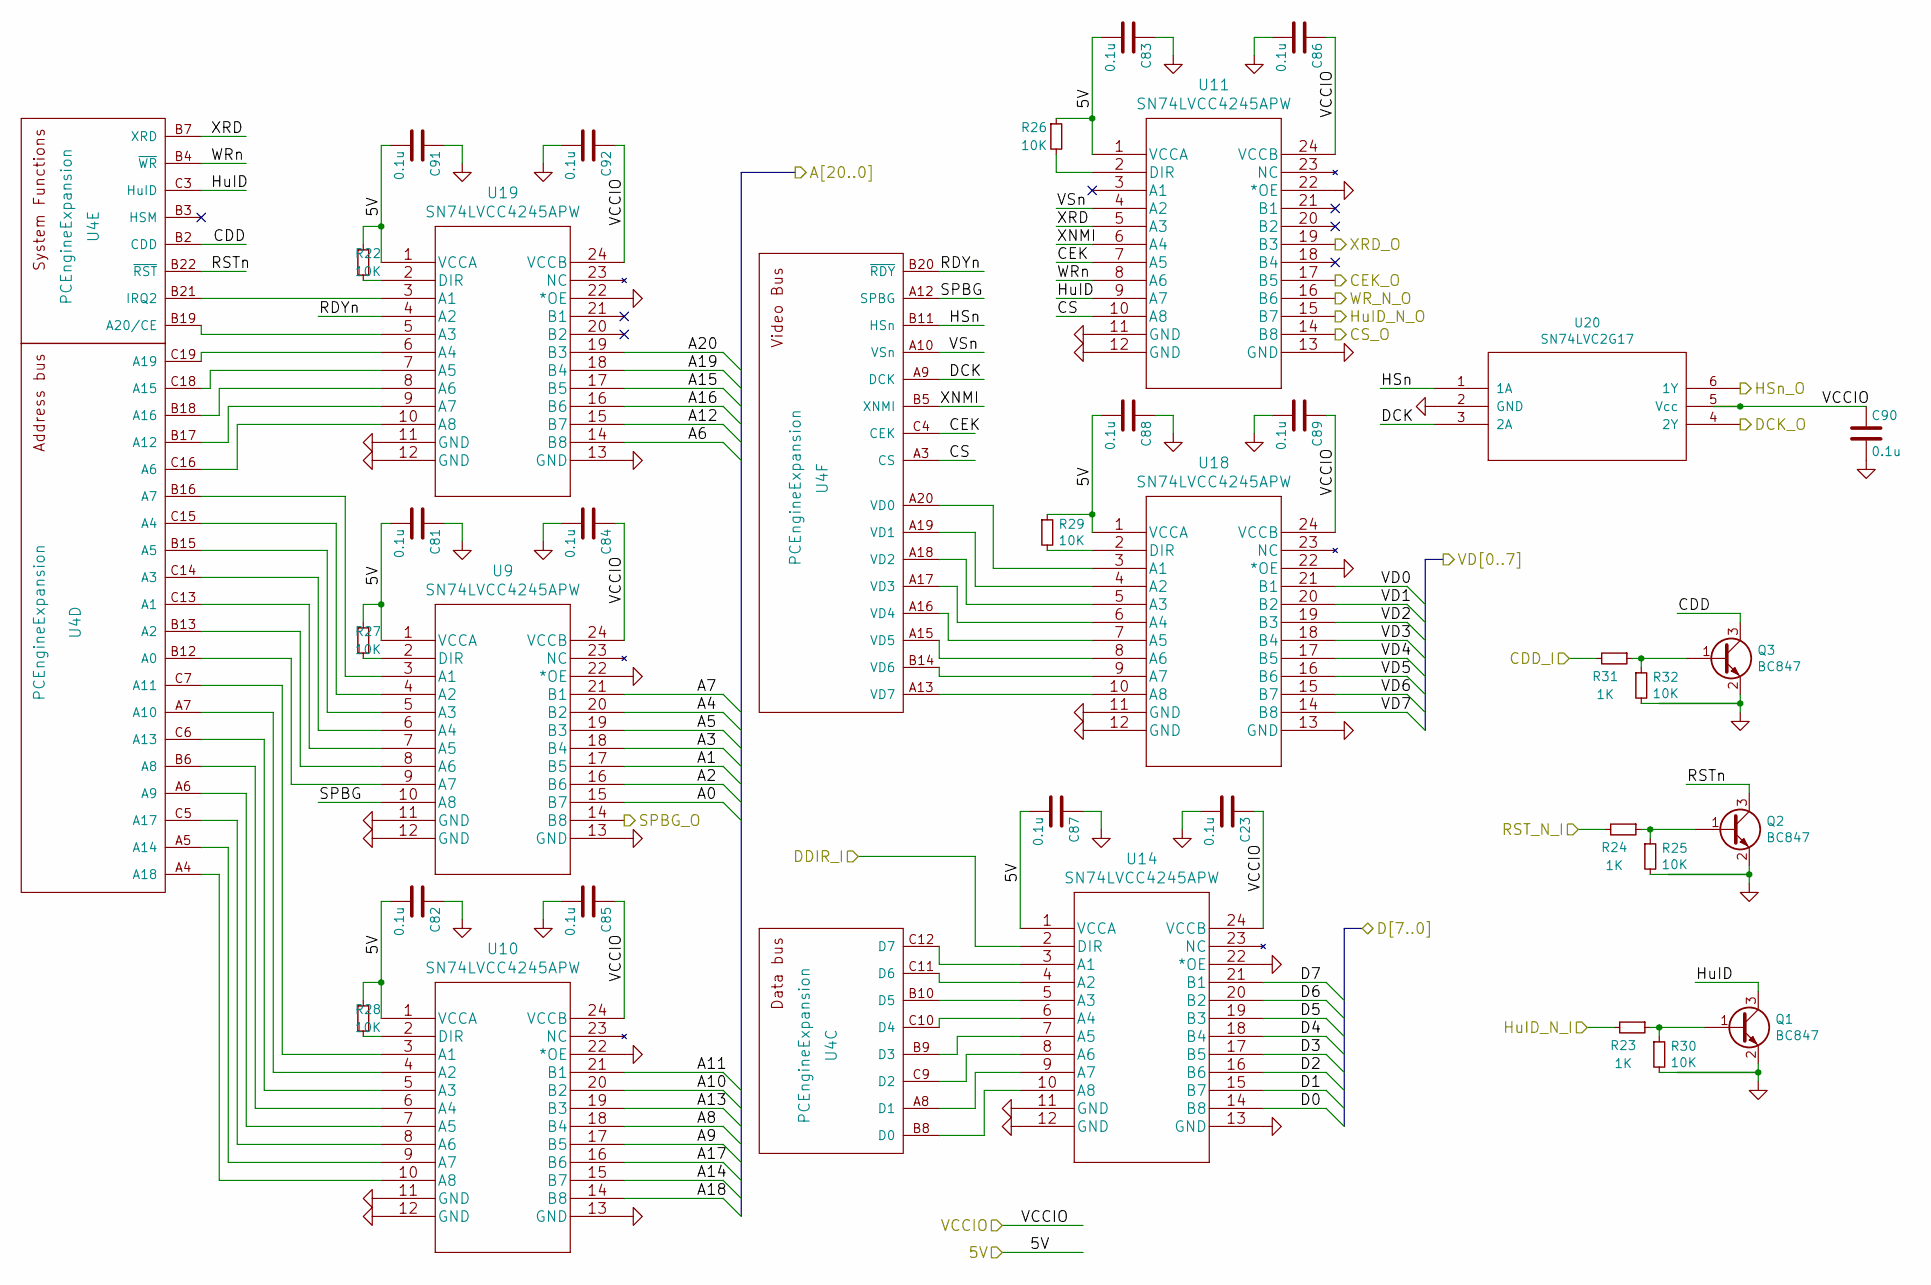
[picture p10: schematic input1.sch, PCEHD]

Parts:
C23, C81, C82, C83, C84, C85, C86, C87, C88, C89, C90, C91, C92: 0.1u; SM0603_Capa_libcms
Q1, Q2, Q3: BC847; SOT-23
R22, R25, R26, R27, R28, R29, R30, R32: 10K; SM0603_Resistor_libcms
R23, R24, R31: 1K; SM0603_Resistor_libcms
U4: PCEngineExpansion
U9, U10, U11, U14, U18, U19: SN74LVCC4245APW
U20: SN74LVC2G17; SOT-23-6_Handsoldering

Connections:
/5V: C81.2, C82.2, C83.2, C87.2, C88.2, C91.2, R22.1, R26.1, R27.1, R28.1, R29.1, U9.1 (VCCA), U10.1 (VCCA), U11.1 (VCCA), U14.1 (VCCA), U18.1 (VCCA), U19.1 (VCCA); also elsewhere on the board
/fpga1/A0: U9.15 (B7); also elsewhere on the board
/fpga1/A1: U9.17 (B5); also elsewhere on the board
/fpga1/A2: U9.16 (B6); also elsewhere on the board
/fpga1/A3: U9.18 (B4); also elsewhere on the board
/fpga1/A4: U9.20 (B2); also elsewhere on the board
/fpga1/A5: U9.19 (B3); also elsewhere on the board
/fpga1/A6: U19.14 (B8); also elsewhere on the board
/fpga1/A7: U9.21 (B1); also elsewhere on the board
/fpga1/A8: U10.18 (B4); also elsewhere on the board
/fpga1/A9: U10.17 (B5); also elsewhere on the board
/fpga1/A10: U10.20 (B2); also elsewhere on the board
/fpga1/A11: U10.21 (B1); also elsewhere on the board
/fpga1/A12: U19.15 (B7); also elsewhere on the board
/fpga1/A13: U10.19 (B3); also elsewhere on the board
/fpga1/A14: U10.15 (B7); also elsewhere on the board
/fpga1/A15: U19.17 (B5); also elsewhere on the board
/fpga1/A16: U19.16 (B6); also elsewhere on the board
/fpga1/A17: U10.16 (B6); also elsewhere on the board
/fpga1/A18: U10.14 (B8); also elsewhere on the board
/fpga1/A19: U19.18 (B4); also elsewhere on the board
/fpga1/A20: U19.19 (B3); also elsewhere on the board
/fpga1/CEK: U11.17 (B5); also elsewhere on the board
/fpga1/CS: U11.14 (B8); also elsewhere on the board
/fpga1/D0: U14.14 (B8); also elsewhere on the board
/fpga1/D1: U14.15 (B7); also elsewhere on the board
/fpga1/D2: U14.16 (B6); also elsewhere on the board
/fpga1/D3: U14.17 (B5); also elsewhere on the board
/fpga1/D4: U14.18 (B4); also elsewhere on the board
/fpga1/D5: U14.19 (B3); also elsewhere on the board
/fpga1/D6: U14.20 (B2); also elsewhere on the board
/fpga1/D7: U14.21 (B1); also elsewhere on the board
/fpga1/DCK: U20.4 (2Y); also elsewhere on the board
/fpga1/DDIR: U14.2 (DIR); also elsewhere on the board
/fpga1/HuID_N: U11.15 (B7); also elsewhere on the board
/fpga1/SPBG: U9.14 (B8); also elsewhere on the board
/fpga1/VD0: U18.21 (B1); also elsewhere on the board
/fpga1/VD1: U18.20 (B2); also elsewhere on the board
/fpga1/VD2: U18.19 (B3); also elsewhere on the board
/fpga1/VD3: U18.18 (B4); also elsewhere on the board
/fpga1/VD4: U18.17 (B5); also elsewhere on the board
/fpga1/VD5: U18.16 (B6); also elsewhere on the board
/fpga1/VD6: U18.15 (B7); also elsewhere on the board
/fpga1/VD7: U18.14 (B8); also elsewhere on the board
/fpga1/WR_N: U11.16 (B6); also elsewhere on the board
/fpga1/XRD: U11.19 (B3); also elsewhere on the board
/input1/CDD: Q3.3 (C), U4.B2 (CDD)
/input1/CDD_I: R31.2; also elsewhere on the board
/input1/CEK: U4.C4 (CEK), U11.7 (A5)
/input1/CS: U4.A3 (CS), U11.10 (A8)
/input1/DCK: U4.A9 (DCK), U20.3 (2A)
/input1/HSn: U4.B11 (HSn), U20.1 (1A)
/input1/HSn_O: U20.6 (1Y); also elsewhere on the board
/input1/HuID: Q1.3 (C), U4.C3 (HuID), U11.9 (A7)
/input1/HuID_N_I: R23.2; also elsewhere on the board
/input1/RDYn: U4.B20 (~RDY), U19.4 (A2)
/input1/RST_N_I: R24.2; also elsewhere on the board
/input1/RSTn: Q2.3 (C), U4.B22 (~RST)
/input1/SPBG: U4.A12 (SPBG), U9.10 (A8)
/input1/VSn: U4.A10 (VSn), U11.4 (A2)
/input1/WRn: U4.B4 (~WR), U11.8 (A6)
/input1/XNMI: U4.B5 (XNMI), U11.6 (A4)
/input1/XRD: U4.B7 (XRD), U11.5 (A3)
GND: C23.2, C81.1, C82.1, C83.1, C84.2, C85.2, C86.2, C87.1, C88.1, C89.2, C90.2, C91.1, C92.2, Q1.2 (E), Q2.2 (E), Q3.2 (E), R25.2, R30.2, R32.2, U9.11 (GND), U9.12 (GND), U9.13 (GND), U9.22 (*OE), U10.11 (GND), U10.12 (GND), U10.13 (GND), U10.22 (*OE), U11.11 (GND), U11.12 (GND), U11.13 (GND), U11.22 (*OE), U14.11 (GND), U14.12 (GND), U14.13 (GND), U14.22 (*OE), U18.11 (GND), U18.12 (GND), U18.13 (GND), U18.22 (*OE), U19.11 (GND), U19.12 (GND), U19.13 (GND), U19.22 (*OE), U20.2 (GND); also elsewhere on the board
unnamed: Q1.1 (B), R23.1, R30.1
unnamed: Q2.1 (B), R24.1, R25.1
unnamed: Q3.1 (B), R31.1, R32.1
unnamed: R22.2, U19.2 (DIR)
unnamed: R26.2, U11.2 (DIR)
unnamed: R27.2, U9.2 (DIR)
unnamed: R28.2, U10.2 (DIR)
unnamed: R29.2, U18.2 (DIR)
unnamed: U4.B12 (A0), U9.9 (A7)
unnamed: U4.B13 (A2), U9.8 (A6)
unnamed: U4.B15 (A5), U9.5 (A3)
unnamed: U4.B16 (A7), U9.3 (A1)
unnamed: U4.C13 (A1), U9.7 (A5)
unnamed: U4.C14 (A3), U9.6 (A4)
unnamed: U4.C15 (A4), U9.4 (A2)
unnamed: U4.C7 (A11), U10.3 (A1)
unnamed: U4.A7 (A10), U10.4 (A2)
unnamed: U4.C6 (A13), U10.5 (A3)
unnamed: U4.B6 (A8), U10.6 (A4)
unnamed: U4.A6 (A9), U10.7 (A5)
unnamed: U4.C5 (A17), U10.8 (A6)
unnamed: U4.A5 (A14), U10.9 (A7)
unnamed: U4.A4 (A18), U10.10 (A8)
unnamed: U4.C12 (D7), U14.3 (A1)
unnamed: U4.C11 (D6), U14.4 (A2)
unnamed: U4.B10 (D5), U14.5 (A3)
unnamed: U4.C10 (D4), U14.6 (A4)
unnamed: U4.B9 (D3), U14.7 (A5)
unnamed: U4.C9 (D2), U14.8 (A6)
unnamed: U4.A8 (D1), U14.9 (A7)
unnamed: U4.B8 (D0), U14.10 (A8)
unnamed: U4.A20 (VD0), U18.3 (A1)
unnamed: U4.A19 (VD1), U18.4 (A2)
unnamed: U4.A18 (VD2), U18.5 (A3)
unnamed: U4.A17 (VD3), U18.6 (A4)
unnamed: U4.A16 (VD4), U18.7 (A5)
unnamed: U4.A15 (VD5), U18.8 (A6)
unnamed: U4.B14 (VD6), U18.9 (A7)
unnamed: U4.A13 (VD7), U18.10 (A8)
unnamed: U4.B21 (IRQ2), U19.3 (A1)
unnamed: U4.B19 (A20/CE), U19.5 (A3)
unnamed: U4.C19 (A19), U19.6 (A4)
unnamed: U4.C18 (A15), U19.7 (A5)
unnamed: U4.B18 (A16), U19.8 (A6)
unnamed: U4.B17 (A12), U19.9 (A7)
unnamed: U4.C16 (A6), U19.10 (A8)
VCC: C23.1, C84.1, C85.1, C86.1, C89.1, C90.1, C92.1, U9.24 (VCCB), U10.24 (VCCB), U11.24 (VCCB), U14.24 (VCCB), U18.24 (VCCB), U19.24 (VCCB), U20.5 (Vcc); also elsewhere on the board

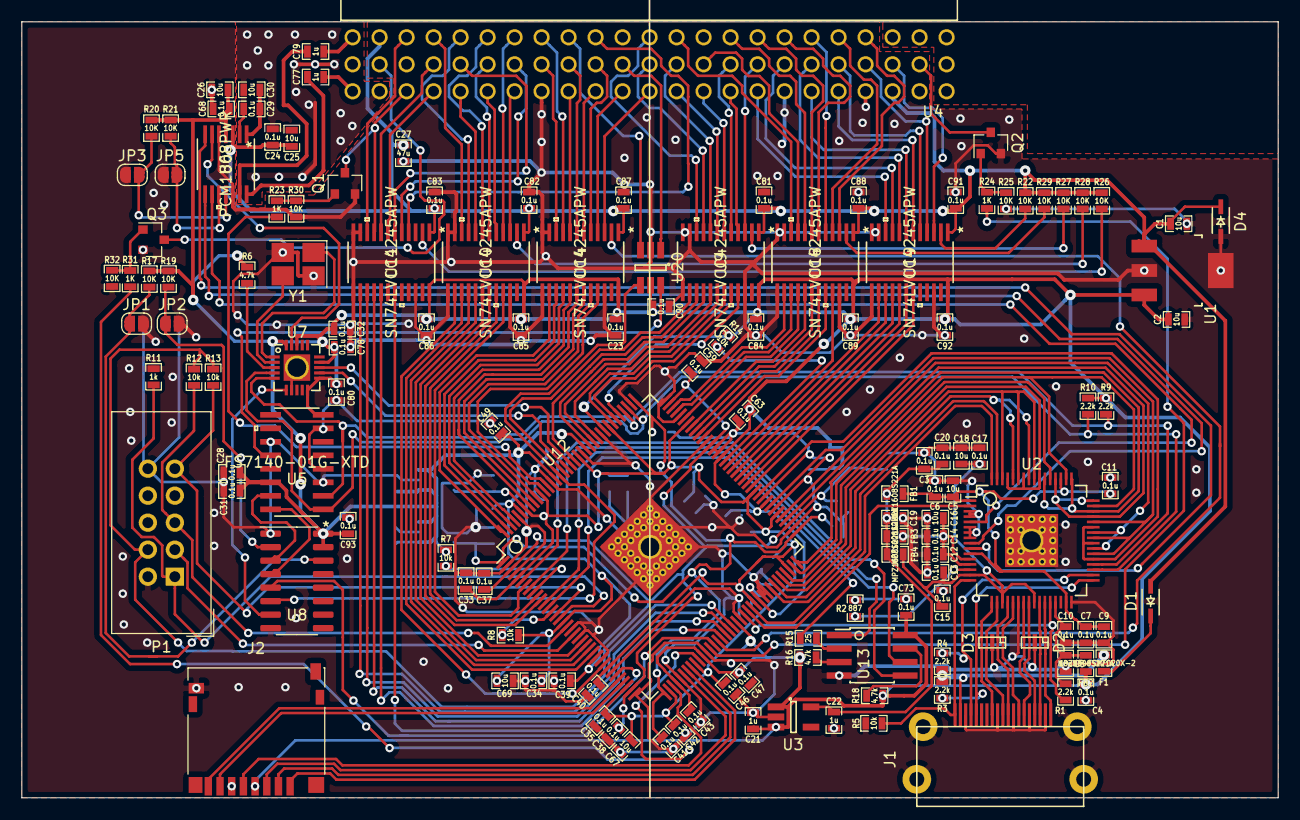
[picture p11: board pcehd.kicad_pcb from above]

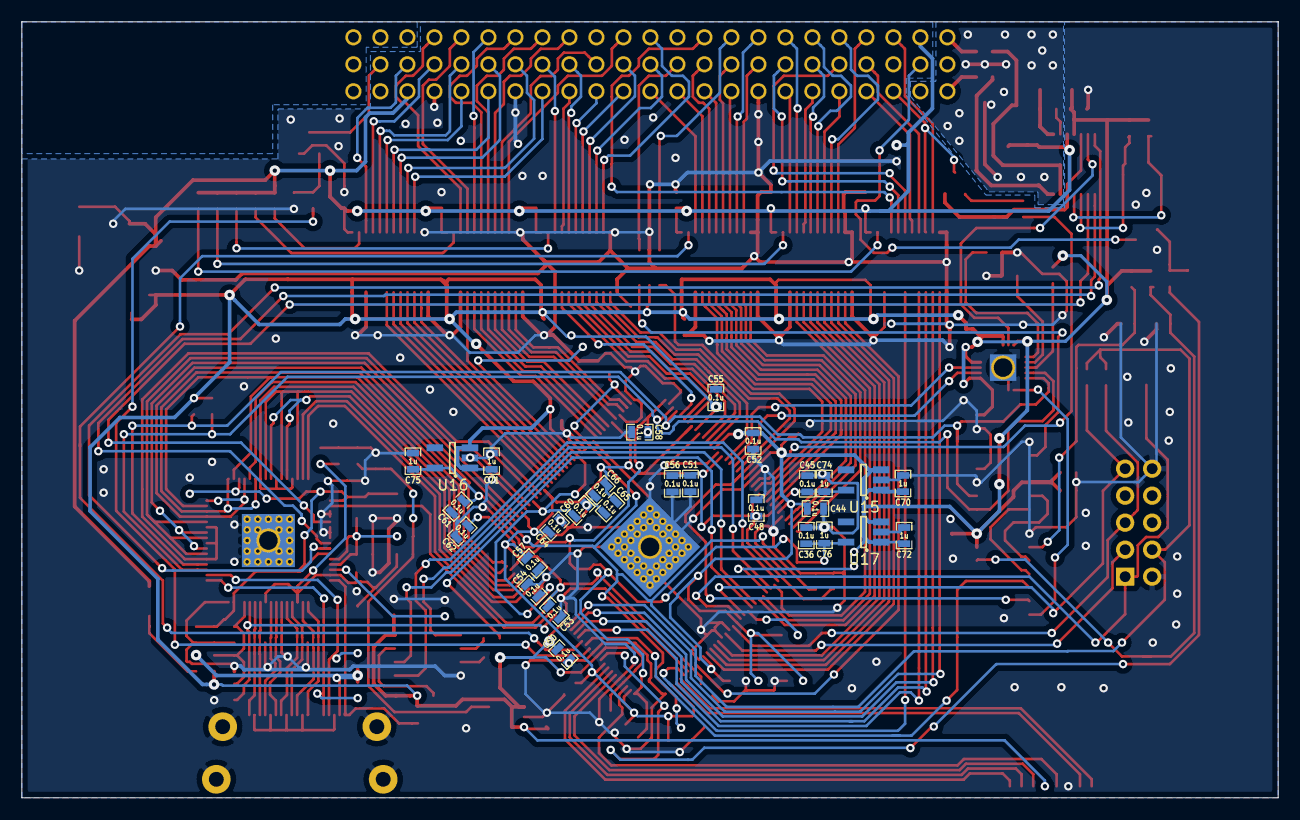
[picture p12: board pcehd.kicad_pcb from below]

Board: 2 copper layers, 118.2 x 73.0 mm, 165 parts (28 on the bottom side), 192 nets.

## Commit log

2020-01-04 Finished initial schematic with audio
    [fpga.sch, hdmitx.sch, input1.sch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]
2020-01-04 Added power unit from expansion connector symbol
    [input1.sch]
2020-01-07 Cleaned up schematic, moved connections to busses
    [fpga.sch, hdmitx.sch, input1.sch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]
2020-01-08 Added clock selection
    [fpga.sch, hdmitx.sch, input1.sch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]
2020-01-13 Added FS7140 PLL, moved to level-shift '245
    [fpga.sch, hdmitx.sch, input1.sch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]
2020-01-13 Assigned footprints, begin layout
    [fpga.sch, input1.sch, pcehd.kicad_pcb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]
2020-01-13 Expansion connection re-order for layout
    [fpga.sch, input1.sch, input2.sch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]
2020-01-14 Layout checkpoint
    [input2.sch, pcehd.kicad_pcb]
2020-01-14 Layout check-in
    [pcehd.kicad_pcb]
2020-01-15 New layout
    [fpga.sch, hdmitx.sch, input1.sch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]
2020-01-15 New layout checkpoint
    [fpga.sch, hdmitx.sch, input1.sch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]
2020-01-16 Removed unneeded jumpers
    [fpga.sch, hdmitx.sch, input1.sch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]
2020-01-17 Layout near complete
    [pcehd.kicad_pcb]
2020-01-17 Layout almost done
    [pcehd.kicad_pcb]
2020-01-17 100% parts placed, 95% routed
    [pcehd.kicad_pcb]
2020-01-18 Removed bypass components and routed all power
    [pcehd.kicad_pcb]
2020-01-18 Finished place and route
    [pcehd.kicad_pcb]
2020-01-19 Added CDD signal to last open IO pin
    [fpga.sch, input1.sch, input2.sch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]
2020-01-20 Finished version 0.1
    [input2.sch, pcehd.kicad_pcb, pcehd.sch]

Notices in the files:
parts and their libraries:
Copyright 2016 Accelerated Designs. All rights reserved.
